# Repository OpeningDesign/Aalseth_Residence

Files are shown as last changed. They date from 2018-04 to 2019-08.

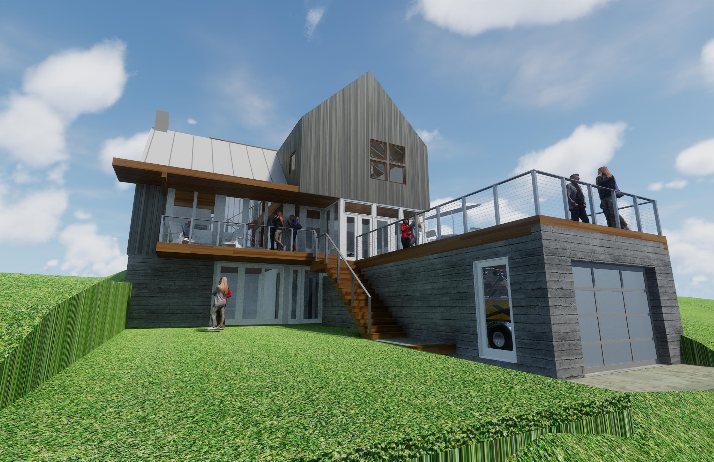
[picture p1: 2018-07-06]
Transfer/20180706 - owner review/jpgs/20180706 - Aalseth_Residence - Schematic Drawings Page 012.jpg

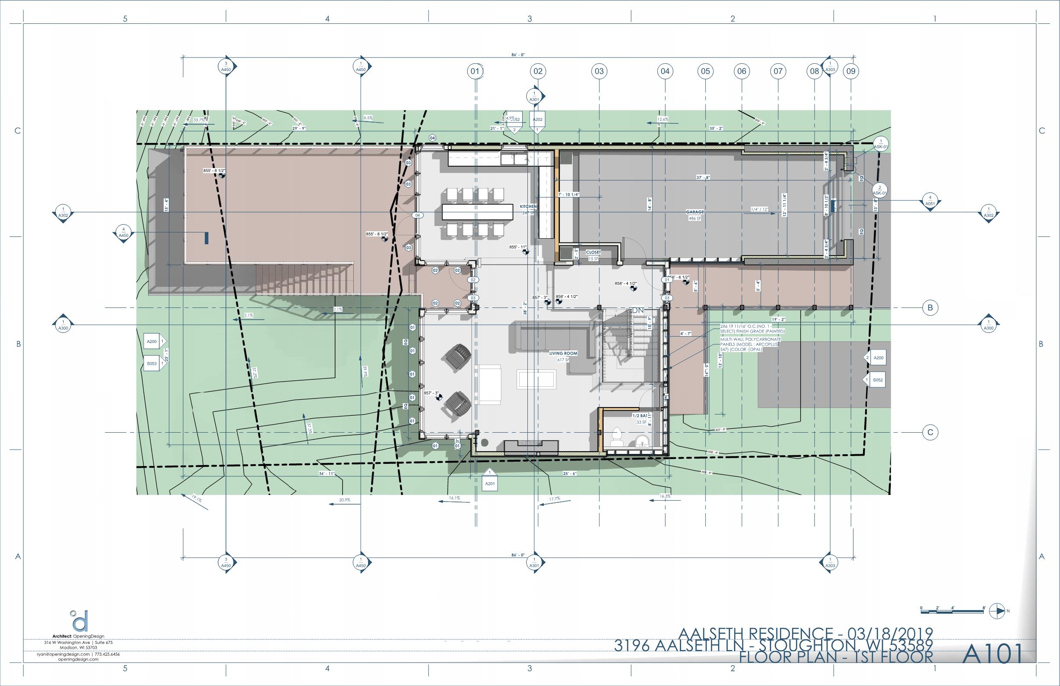
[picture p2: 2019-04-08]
Transfer/20190321 - to lumber yard - latest plans with door and window schedule/20190318 - 3196 Aalseth Lane Page 002.jpg

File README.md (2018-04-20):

---
#### In-the-Open

All of [OpeningDesign's](http://openingdesign.com/) projects are conducted out in the open.  That is, during the development of any one project, all team communication and content is hosted [publicly](https://github.com/OpeningDesign) (here on GitHub) and is <a href="#license">open source</a>.

Our [about page](http://openingdesign.com/about/) provides a more nuanced description of this open approach.

---
#### License
Per usual, unless otherwise noted, all content associated with [OpeningDesign](http://openingdesign.com) projects is licensed under an open source, 'copyleft' license: 
[Attribution-ShareAlike 4.0 International (CC BY-SA 4.0)](https://creativecommons.org/licenses/by-sa/4.0/).  Attribution to be given to the entire team associated with the project.


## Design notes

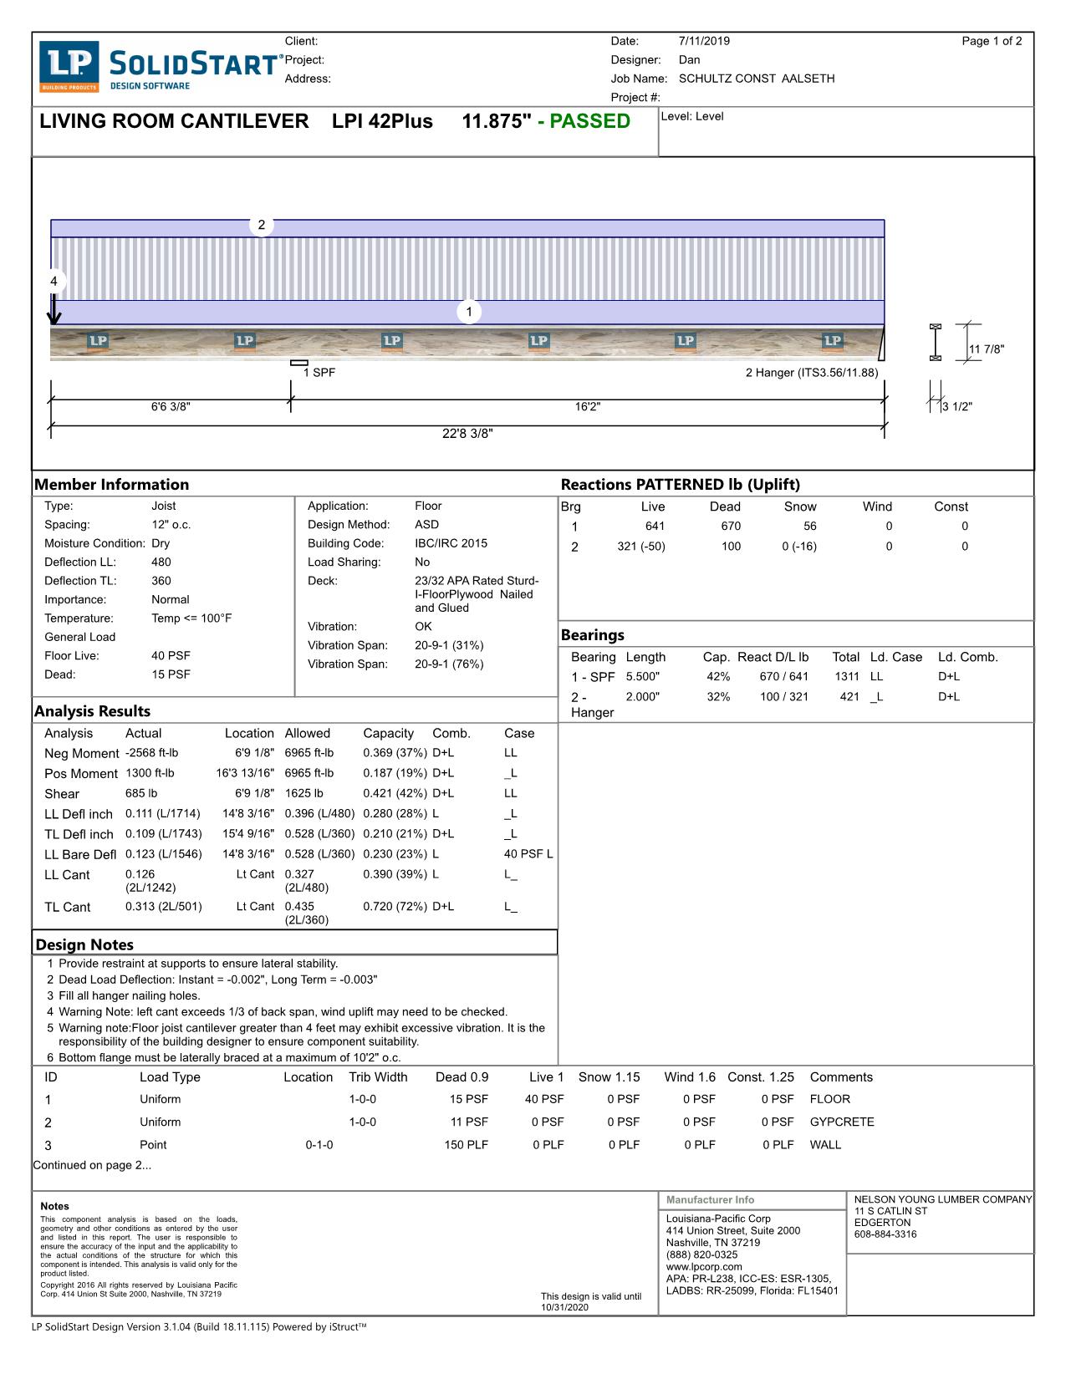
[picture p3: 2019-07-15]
Transfer/20190711 - from Lumber Yard - TJI spec/SCHULTZ AALSETH LIVING ROOM JOIST CANTILEVER Page 001.jpg

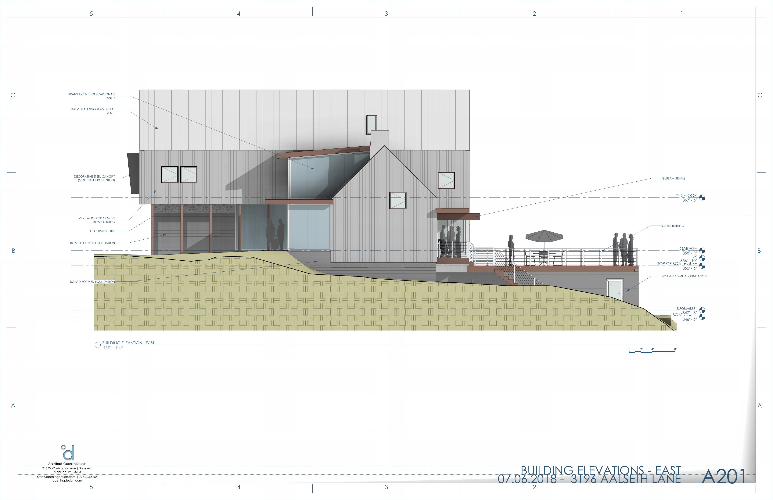
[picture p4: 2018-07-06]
Transfer/20180706 - owner review/jpgs/20180706 - Aalseth_Residence - Schematic Drawings Page 006.jpg

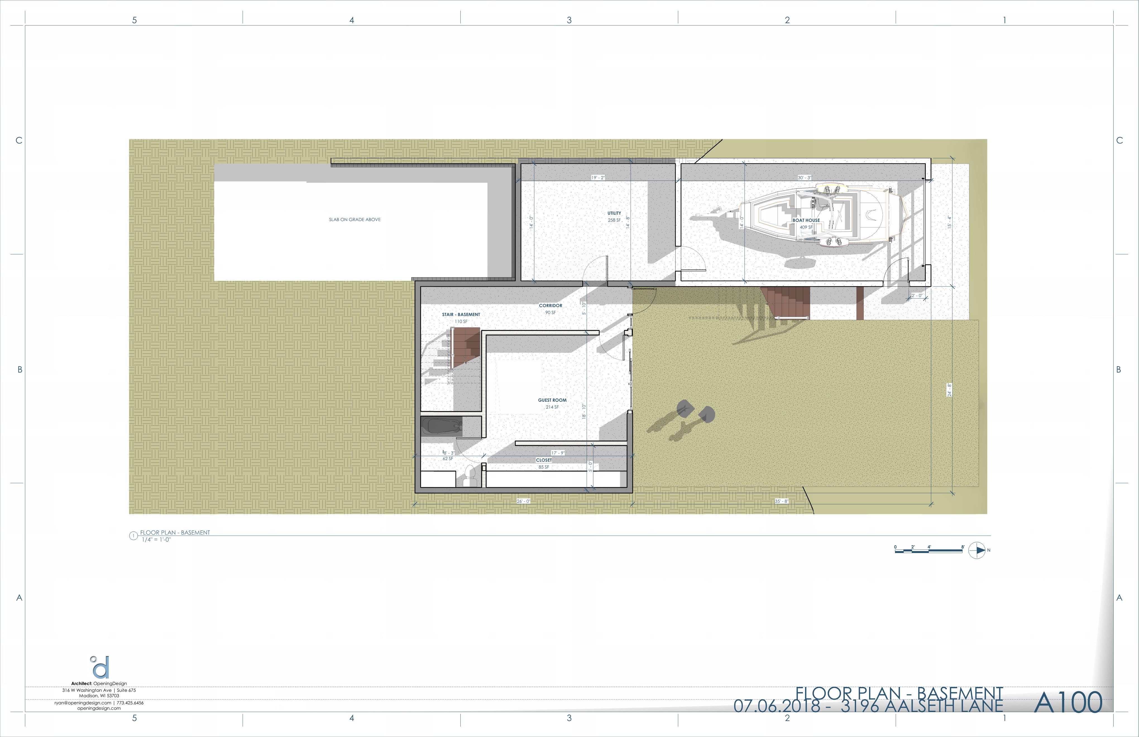
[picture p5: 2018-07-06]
Transfer/20180706 - owner review/jpgs/20180706 - Aalseth_Residence - Schematic Drawings Page 002.jpg

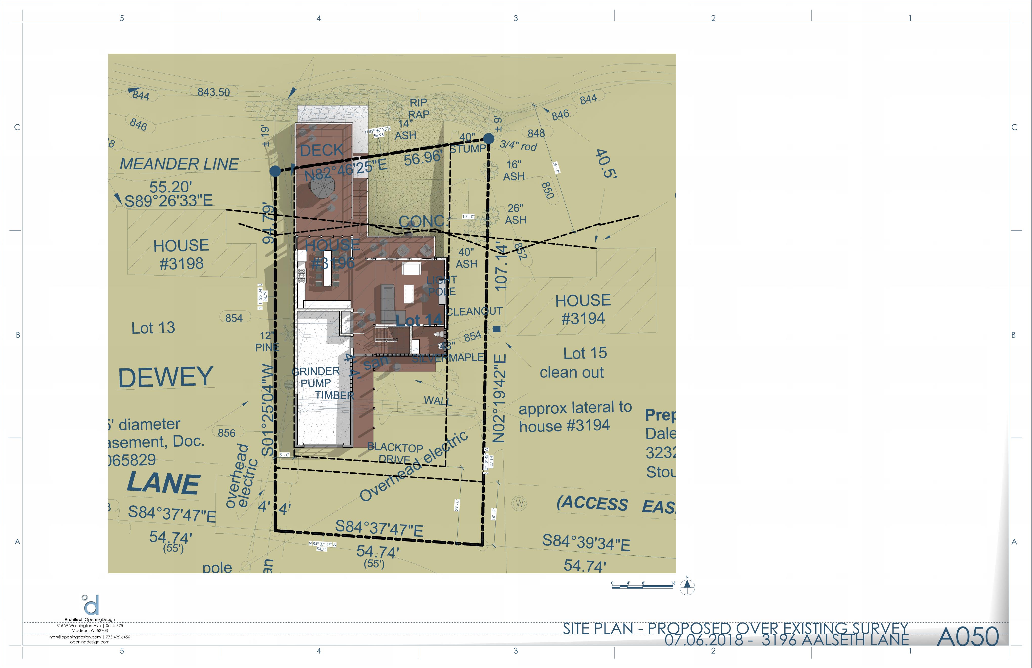
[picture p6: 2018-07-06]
Transfer/20180706 - owner review/jpgs/20180706 - Aalseth_Residence - Schematic Drawings Page 001.jpg

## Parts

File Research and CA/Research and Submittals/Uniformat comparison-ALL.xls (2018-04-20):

A | Substructure | 1 |  |  | A | Substructure | 1 |  | 21-01 00 00 | Substructure
B | Shell | 1 |  |  | A2010310 | Shoring | 5 | -2001300 | 21-02 00 00 | Shell
C | Interiors | 1 |  |  | B1020230 | Beams - Steel | 5 | -2001320 | 21-03 00 00 | Interiors
D | Services | 1 |  |  | B2030900 | Other Exterior Doors | 4 | -2000023 | 21-04 00 00 | Services
E | Equipment and Furnishings | 1 |  |  | D1020110 | Escalators | 5 | -2001350 | 21-05 00 00 | Equipment and Furnishings
F | Special Construction and Demolition | 1 |  |  | D2040 | Rain Water Drainage | 3 | -2001160 | 21-06 00 00 | Special Construction and Demolition
G | Sitework | 1 |  |  | D3090 | Other HVAC Systems/Equip | 3 | -2001140 | 21-07 00 00 | Sitework
A10 | Foundations | 2 | 0 |  | A10 | Foundations | 2 |  | 21-01 10 | Foundations
A20 | Subgrade Enclosures | 2 | 0 |  | A1020100 | Pile Foundations | 4 | -2001300 | 21-01 20 | Subgrade Enclosures
A40 | Slabs-On-Grade | 2 | 0 |  | A1020150 | Piles - Step Tapered | 5 | -2001300 | 21-01 40 | Slabs-On-Grade
A60 | Water and Gas Mitigation | 2 | 0 |  | A1020900 | Other Special Foundation Conditions | 4 | -2001300 | 21-01 60 | Water and Gas Mitigation
A90 | Substructure Related Activities | 2 | 0 |  | A1030400 | Trenches | 4 | -2001300 | 21-01 90 | Substructure Related Activities
B10 | Superstructure | 2 | 0 |  | A2020 | Basement Walls | 3 |  | 21-02 10 | Superstructure
B20 | Exterior Vertical Enclosures | 2 | 0 |  | B1010245 | Columns - Precast | 5 | -2001330 | 21-02 20 | Exterior Vertical Enclosures
B30 | Exterior Horizontal Enclosures | 2 | 0 |  | B1010480 | Wood Beams w/ Wood Joists | 5 | -2001320 | 21-02 30 | Exterior Horizontal Enclosures
C10 | Interior Construction | 2 | 0 |  | B1020240 | Beams - Wood (Dimensional Lumber) | 5 | -2001320 | 21-03 10 | Interior Construction
C20 | Interior Finishes | 2 | 0 |  | B2010152 | Ext. Wall - Brick (Double Wythe) | 5 | -2000011 | 21-03 20 | Interior Finishes
D10 | Conveying | 2 | 0 |  | B30 | Roofing | 2 |  | 21-04 10 | Conveying
D20 | Plumbing | 2 | 0 |  | B3020300 | Gravity Roof Ventilators | 4 | -2001140 | 21-04 20 | Plumbing
D30 | Heating, Ventilation, and Air Conditioning (HVAC) | 2 | 0 |  | C1010600 | Interior Balustrades & Screens | 4 | -2000126 | 21-04 30 | Heating, Ventilation, and Air Conditioning (HVAC)
D40 | Fire Protection | 2 | 0 |  | C1030400 | Fabricated Cabinets & Counters | 4 | -2001000 | 21-04 40 | Fire Protection
D50 | Electrical | 2 | 0 |  | C1030900 | Other Fittings | 4 | -2001350 | 21-04 50 | Electrical
D60 | Communications | 2 | 0 |  | C3020100 | Floor Toppings & Coatings | 4 | -2000032 | 21-04 60 | Communications
D70 | Electronic Safety and Security | 2 | 0 |  | C3030 | Ceiling Finishes | 3 |  | 21-04 70 | Electronic Safety and Security
D80 | Integrated Automation | 2 | 0 |  | D1010100 | Passenger Elevators | 4 | -2001350 | 21-04 80 | Integrated Automation
E10 | Equipment | 2 | 0 |  | D1020200 | Moving Walks | 4 | -2001350 | 21-05 10 | Equipment
E20 | Furnishings | 2 | 0 |  | D2010820 | Water Coolers | 5 | -2001160 | 21-05 20 | Furnishings
F10 | Special Construction | 2 | 0 |  | D2040100 | Pipe & Fittings | 4 | -2001160 | 21-06 10 | Special Construction
F20 | Facility Remediation | 2 | 0 |  | D3040400 | Hot Water Distribution | 4 | -2001140 | 21-06 20 | Facility Remediation
F30 | Demolition | 2 | 0 |  | D3060 | Controls & Instrumentation | 3 | -2001140 | 21-06 30 | Demolition
G10 | Site Preparation | 2 | 0 |  | D3090100 | Special Cooling Systems & Devices | 4 | -2001140 | 21-07 10 | Site Preparation
G20 | Site Improvements | 2 | 0 |  | D5020110 | Receptacles - Wall | 5 | -2001060 | 21-07 20 | Site Improvements
G30 | Liquid and Gas Site Utilities | 2 | 0 |  | E1020300 | Theater & Stage Equipment | 4 | -2001350 | 21-07 30 | Liquid and Gas Site Utilities
G40 | Electrical Site Improvements | 2 | 0 |  | E20 | Furnishings | 2 |  | 21-07 40 | Electrical Site Improvements
G50 | Site Communications | 2 | 0 |  | E2020300 | Movable Rugs & Mats | 4 | -2000080 | 21-07 50 | Site Communications
G90 | Miscellaneous Site Construction | 2 | 0 |  | F1010 | Special Structures | 3 |  | 21-07 90 | Miscellaneous Site Construction
A1010 | Standard Foundations | 3 | 0 |  | A1010 | Standard Foundations | 3 |  | 21-01 10 10 | Standard Foundations
A1020 | Special Foundations | 3 | 0 |  | A1010130 | Pile Caps | 5 | -2001300 | 21-01 10 20 | Special Foundations
A2010 | Walls for Subgrade Enclosures | 3 | 0 |  | A1020110 | Piles - CIP | 5 | -2001300 | 21-01 20 10 | Walls for Subgrade Enclosures
A4010 | Standard Slabs-on-Grade | 3 | 0 |  | A1020160 | Piles - Treated Wood | 5 | -2001300 | 21-01 40 10 | Standard Slabs-on-Grade
A4020 | Structural Slabs-on-Grade | 3 | 0 |  | A1020200 | Grade Beams | 4 | -2001300 | 21-01 40 20 | Structural Slabs-on-Grade
A4030 | Slab Trenches | 3 | 0 |  | A1020210 | Grade Beams - CIP | 5 | -2001300 | 21-01 40 30 | Slab Trenches
A4040 | Pits and Bases | 3 | 0 |  | A1020300 | Caissons | 4 | -2001300 | 21-01 40 40 | Pits and Bases
A4090 | Slab-On-Grade Supplementary Components | 3 | 0 |  | A1020310 | Caissons - Bell | 5 | -2001300 | 21-01 40 90 | Slab-On-Grade Supplementary Components
A6010 | Building Subdrainage | 3 | 0 |  | A1030 | Slab on Grade | 3 |  | 21-01 60 10 | Building Subdrainage
A6020 | Off-Gassing Mitigation | 3 | 0 |  | A1030120 | SOG - Unreinforced | 5 | -2000032 | 21-01 60 20 | Off-Gassing Mitigation
A9010 | Substructure Excavation | 3 | 0 |  | A1030500 | Pits & Bases | 4 | -2001300 | 21-01 90 10 | Substructure Excavation
A9020 | Construction Dewatering | 3 | 0 |  | A1030700 | Under-Slab Insulation | 4 | -2000032 | 21-01 90 20 | Construction Dewatering
A9030 | Excavation Support | 3 | 0 |  | A1030710 | Subdrainage Piping | 5 | -2001160 | 21-01 90 30 | Excavation Support
A9040 | Soil Treatment | 3 | 0 |  | A2010300 | Shoring | 4 | -2001300 | 21-01 90 40 | Soil Treatment
B1010 | Floor Construction | 3 | 0 |  | A2020100 | Basement Wall Construction | 4 | -2000011 | 21-02 10 10 | Floor Construction
B1020 | Roof Construction | 3 | 0 |  | A2020310 | Basement Wall Insulation - Rigid | 5 | -2000011 | 21-02 10 20 | Roof Construction
B1080 | Stairs | 3 | 0 |  | B1010100 | Suspended Basement Floor Construction | 4 | -2000032 | 21-02 10 80 | Stairs
B2010 | Exterior Walls | 3 | 0 |  | B1010250 | Columns - Steel | 5 | -2001330 | 21-02 20 10 | Exterior Walls
B2020 | Exterior Windows | 3 | 0 |  | B1010350 | Joists - Steel | 5 | -2001320 | 21-02 20 20 | Exterior Windows
B2050 | Exterior Doors and Grilles | 3 | 0 |  | B1010380 | Planks - Precast | 5 | -2000032 | 21-02 20 50 | Exterior Doors and Grilles
B2070 | Exterior Louvers and Vents | 3 | 0 |  | B1010422 | CIP Beam & Slab - Two Way | 5 | -2001320 | 21-02 20 70 | Exterior Louvers and Vents
B2080 | Exterior Wall Appurtenances | 3 | 0 |  | B1010434 | W Shape Composite Deck & Slab | 5 | -2001320 | 21-02 20 80 | Exterior Wall Appurtenances
B2090 | Exterior Wall Specialties | 3 | 0 |  | B1010470 | Steel Light Gauge Floor System | 5 | -2001320 | 21-02 20 90 | Exterior Wall Specialties
B3010 | Roofing | 3 | 0 |  | B1010482 | Wood Laminated Beams w/ Wood Joists | 5 | -2001320 | 21-02 30 10 | Roofing
B3020 | Roof Appurtenances | 3 | 0 |  | B1010900 | Fireproofing - Floor Construction | 4 | -2000032 | 21-02 30 20 | Roof Appurtenances
B3040 | Traffic Bearing Horizontal Enclosures | 3 | 0 |  | B1020100 | Flat Roof Framing - Vertical Elements | 4 | -2000011 | 21-02 30 40 | Traffic Bearing Horizontal Enclosures
B3060 | Horizontal Openings | 3 | 0 |  | B1020140 | Columns - CIP | 5 | -2001330 | 21-02 30 60 | Horizontal Openings
B3080 | Overhead Exterior Enclosures | 3 | 0 |  | B1020200 | Flat Roof Framing - Horizontal Elements | 4 | -2001320 | 21-02 30 80 | Overhead Exterior Enclosures
C1010 | Interior Partitions | 3 | 0 |  | B1020245 | Beams - Wood (Laminated) | 5 | -2001320 | 21-03 10 10 | Interior Partitions
C1020 | Interior Windows | 3 | 0 |  | B1020300 | Flat Roof Framing - Systems | 4 | -2000035 | 21-03 10 20 | Interior Windows
C1030 | Interior Doors | 3 | 0 |  | B1020318 | CIP Slabs - Waffle | 5 | -2000035 | 21-03 10 30 | Interior Doors
C1040 | Interior Grilles and Gates | 3 | 0 |  | B1020364 | Joist Girders w/ Steel Joists | 5 | -2001320 | 21-03 10 40 | Interior Grilles and Gates
C1060 | Raised Floor Construction | 3 | 0 |  | B1020382 | Wood Laminated Beams w/ Wood Joists | 5 | -2001320 | 21-03 10 60 | Raised Floor Construction
C1070 | Suspended Ceiling Construction | 3 | 0 |  | B1020600 | Dome Construction | 4 | -2000035 | 21-03 10 70 | Suspended Ceiling Construction
C1090 | Interior Specialties | 3 | 0 |  | B20 | Exterior Enclosure | 2 |  | 21-03 10 90 | Interior Specialties
C2010 | Wall Finishes | 3 | 0 |  | B2010154 | Ext. Wall - Brick Cavity | 5 | -2000011 | 21-03 20 10 | Wall Finishes
C2020 | Interior Fabrications | 3 | 0 |  | B2010400 | Exterior Sun Control Devices | 4 | -2001140 | 21-03 20 20 | Interior Fabrications
C2030 | Flooring | 3 | 0 |  | B2010500 | Balcony Walls & Handrails | 4 | -2000126 | 21-03 20 30 | Flooring
C2040 | Stair Finishes | 3 | 0 |  | B2030100 | Glazed Doors & Entrances | 4 | -2000023 | 21-03 20 40 | Stair Finishes
C2050 | Ceiling Finishes | 3 | 0 |  | B2030230 | Exterior Solid Doors - Wood | 5 | -2000023 | 21-03 20 50 | Ceiling Finishes
D1010 | Vertical Conveying Systems | 3 | 0 |  | B3010 | Roof Coverings | 3 |  | 21-04 10 10 | Vertical Conveying Systems
D1030 | Horizontal Conveying | 3 | 0 |  | B3010150 | Roofing - Shingle & Tile | 5 | -2000035 | 21-04 10 30 | Horizontal Conveying
D1050 | Material Handling | 3 | 0 |  | B3010410 | Base Flashing | 5 | -2000035 | 21-04 10 50 | Material Handling
D1080 | Operable Access Systems | 3 | 0 |  | B3020100 | Glazed Roof Openings | 4 | -2000014 | 21-04 10 80 | Operable Access Systems
D2010 | Domestic Water Distribution | 3 | 0 |  | C | Interiors | 1 |  | 21-04 20 10 | Domestic Water Distribution
D2020 | Sanitary Drainage | 3 | 0 |  | C1010118 | Partitions - Stone Veneer w/ Stud | 5 | -2000011 | 21-04 20 20 | Sanitary Drainage
D2030 | Building Support Plumbing Systems | 3 | 0 |  | C1010140 | Partitions - Drywall w/ Wood Stud | 5 | -2000011 | 21-04 20 30 | Building Support Plumbing Systems
D2050 | General Service Compressed-Air | 3 | 0 |  | C1010190 | Partition Components - Drywall | 5 | -2000011 | 21-04 20 50 | General Service Compressed-Air
D2060 | Process Support Plumbing Systems | 3 | 0 |  | C1010195 | Partition Components - Plaster | 5 | -2000011 | 21-04 20 60 | Process Support Plumbing Systems
D3010 | Facility Fuel Systems | 3 | 0 |  | C1010700 | Interior Windows & Storefronts | 4 | -2000014 | 21-04 30 10 | Facility Fuel Systems
D3020 | Heating Systems | 3 | 0 |  | C1020110 | Interior Doors - Metal | 5 | -2000023 | 21-04 30 20 | Heating Systems
D3030 | Cooling Systems | 3 | 0 |  | C1020300 | Interior Doors with Frames | 4 | -2000023 | 21-04 30 30 | Cooling Systems
D3050 | Facility HVAC Distribution Systems | 3 | 0 |  | C1020500 | Interior Door Wall Opening Elements | 4 | -2000023 | 21-04 30 50 | Facility HVAC Distribution Systems
D3060 | Ventilation | 3 | 0 |  | C1030110 | Toilet Partitions | 5 | -2001160 | 21-04 30 60 | Ventilation
D3070 | Special Purpose HVAC Systems | 3 | 0 |  | C1030320 | Shelving | 5 | -2001350 | 21-04 30 70 | Special Purpose HVAC Systems
D4010 | Fire Suppression | 3 | 0 |  | C1030410 | Cabinets | 5 | -2001000 | 21-04 40 10 | Fire Suppression
D5010 | Facility Power Generation | 3 | 0 |  | C1030910 | Mailboxes | 5 | -2001350 | 21-04 50 10 | Facility Power Generation
D5020 | Electrical Service and Distribution | 3 | 0 |  | C2010200 | Curved Stairs | 4 | -2000120 | 21-04 50 20 | Electrical Service and Distribution
D5030 | General Purpose Electrical Power | 3 | 0 |  | C2020 | Stair Finishes | 3 |  | 21-04 50 30 | General Purpose Electrical Power
D5040 | Lighting | 3 | 0 |  | C30 | Interior Finishes | 2 |  | 21-04 50 40 | Lighting
D5080 | Miscellaneous Electrical Systems | 3 | 0 |  | C3010130 | Wall Finishes - Coverings | 5 | -2000011 | 21-04 50 80 | Miscellaneous Electrical Systems
D6010 | Data Communications | 3 | 0 |  | C3020110 | Concrete Toppings | 5 | -2000032 | 21-04 60 10 | Data Communications
D6020 | Voice Communications | 3 | 0 |  | C3020410 | Flooring - Sheet Goods | 5 | -2000032 | 21-04 60 20 | Voice Communications
D6030 | Audio-Video Communication | 3 | 0 |  | C3020500 | Carpeting | 4 | -2000032 | 21-04 60 30 | Audio-Video Communication
D6090 | Communications Supplementary Components | 3 | 0 |  | C3020800 | Subflooring & Underlayment | 4 | -2000032 | 21-04 60 90 | Communications Supplementary Components
D7010 | Access Control and Intrusion Detection | 3 | 0 |  | C3030100 | Applied Ceiling Finishes | 4 | -2000038 | 21-04 70 10 | Access Control and Intrusion Detection
D7030 | Electronic Surveillance | 3 | 0 |  | C3030130 | Ceiling Finishes - Coverings | 5 | -2000038 | 21-04 70 30 | Electronic Surveillance
D7050 | Detection and Alarm | 3 | 0 |  | C3030200 | Suspended Ceilings | 4 | -2000038 | 21-04 70 50 | Detection and Alarm
D7070 | Electronic Monitoring and Control | 3 | 0 |  | C3030900 | Other Ceiling Finishes | 4 | -2000038 | 21-04 70 70 | Electronic Monitoring and Control
D7090 | Electronic Safety and Security Supplementary Components | 3 | 0 |  | D10 | Conveying | 2 |  | 21-04 70 90 | Electronic Safety and Security Supplementary Components
D8010 | Integrated Automation Facility Controls | 3 | 0 |  | D1010110 | Elevators - Hydraulic | 5 | -2001350 | 21-04 80 10 | Integrated Automation Facility Controls
E1010 | Vehicle and Pedestrian Equipment | 3 | 0 |  | D1020210 | Moving Walks | 5 | -2001350 | 21-05 10 10 | Vehicle and Pedestrian Equipment
E1030 | Commercial Equipment | 3 | 0 |  | D1090400 | Conveyors | 4 | -2001350 | 21-05 10 30 | Commercial Equipment
E1040 | Institutional Equipment | 3 | 0 |  | D2010120 | Water Closets - Group | 5 | -2001160 | 21-05 10 40 | Institutional Equipment
E1060 | Residential Equipment | 3 | 0 |  | D2010320 | Lavatories - Battery Mount | 5 | -2001160 | 21-05 10 60 | Residential Equipment
E1070 | Entertainment and Recreational Equipment | 3 | 0 |  | D2010430 | Sinks - Laboratory | 5 | -2001160 | 21-05 10 70 | Entertainment and Recreational Equipment
E1090 | Other Equipment | 3 | 0 |  | D2010610 | Wash Fountains - Group | 5 | -2001160 | 21-05 10 90 | Other Equipment
E2010 | Fixed Furnishings | 3 | 0 |  | D2010900 | Other Plumbing Fixtures | 4 | -2001160 | 21-05 20 10 | Fixed Furnishings
E2050 | Movable Furnishings | 3 | 0 |  | D2030 | Sanitary Waste | 3 | -2001160 | 21-05 20 50 | Movable Furnishings
F1010 | Integrated Construction | 3 | 0 |  | D2040200 | Roof Drains | 4 | -2001160 | 21-06 10 10 | Integrated Construction
F1020 | Special Structures | 3 | 0 |  | D2090100 | Gas Distribution | 4 | -2001160 | 21-06 10 20 | Special Structures
F1030 | Special Function Construction | 3 | 0 |  | D30 | HVAC | 2 |  | 21-06 10 30 | Special Function Construction
F1050 | Special Facility Components | 3 | 0 |  | D3010300 | Coal Supply System | 4 | -2001140 | 21-06 10 50 | Special Facility Components
F1060 | Athletic and Recreational Special Construction | 3 | 0 |  | D3020100 | Boilers | 4 | -2001140 | 21-06 10 60 | Athletic and Recreational Special Construction
F1080 | Special Instrumentation | 3 | 0 |  | D3030300 | Other Cooling System Components | 4 | -2001140 | 21-06 10 80 | Special Instrumentation
F2010 | Hazardous Materials Remediation | 3 | 0 |  | D3040500 | Chilled Water Distribution | 4 | -2001140 | 21-06 20 10 | Hazardous Materials Remediation
F3010 | Structure Demolition | 3 | 0 |  | D3060100 | Heating Generating Systems | 4 | -2001140 | 21-06 30 10 | Structure Demolition
F3030 | Selective Demolition | 3 | 0 |  | D3060600 | Terminal Devices | 4 | -2001140 | 21-06 30 30 | Selective Demolition
F3050 | Structure Moving | 3 | 0 |  | D3070200 | Air System Testing & Balancing | 4 | -2001140 | 21-06 30 50 | Structure Moving
G1010 | Site Clearing | 3 | 0 |  | D3090200 | Special Humidity Control | 4 | -2001140 | 21-07 10 10 | Site Clearing
G1020 | Site Elements Demolition | 3 | 0 |  | D3090600 | Paint Spray Booth Ventilation | 4 | -2001140 | 21-07 10 20 | Site Elements Demolition
G1030 | Site Element Relocations | 3 | 0 |  | D4010 | Sprinklers | 3 |  | 21-07 10 30 | Site Element Relocations
G1050 | Site Remediation | 3 | 0 |  | D4010200 | Sprinkler Pumping Equipment | 4 | -2001160 | 21-07 10 50 | Site Remediation
G1070 | Site Earthwork | 3 | 0 |  | D4030900 | Other Fire Protection Specialties | 4 | -2001350 | 21-07 10 70 | Site Earthwork
G2010 | Roadways | 3 | 0 |  | D5020115 | Receptacles - Floor | 5 | -2001060 | 21-07 20 10 | Roadways
G2020 | Parking Lots | 3 | 0 |  | D5020280 | Light Poles | 5 | -2001120 | 21-07 20 20 | Parking Lots
G2030 | Pedestrian Plazas and Walkways | 3 | 0 |  | D5030500 | Television Systems | 4 | -2001040 | 21-07 20 30 | Pedestrian Plazas and Walkways
G2040 | Airfields | 3 | 0 |  | D5090200 | Emergency Light & Power Systems | 4 | -2001040 | 21-07 20 40 | Airfields
G2050 | Athletic, Recreational, and Playfield Areas | 3 | 0 |  | E1010 | Commercial Equipment | 3 |  | 21-07 20 50 | Athletic, Recreational, and Playfield Areas
G2060 | Site Development | 3 | 0 |  | E1010200 | Teller & Service Equipment | 4 | -2001350 | 21-07 20 60 | Site Development
G2080 | Landscaping | 3 | 0 |  | E1020100 | Ecclesiastical Equipment | 4 | -2001350 | 21-07 20 80 | Landscaping
G3010 | Water Utilities | 3 | 0 |  | E1020310 | Theater Equipment - Projection | 5 | -2001350 | 21-07 30 10 | Water Utilities
G3020 | Sanitary Sewerage Utilities | 3 | 0 |  | E1020500 | Audio-visual Equipment | 4 | -2001350 | 21-07 30 20 | Sanitary Sewerage Utilities
G3030 | Storm Drainage Utilities | 3 | 0 |  | E1020800 | Medical Equipment | 4 | -2001350 | 21-07 30 30 | Storm Drainage Utilities
G3050 | Site Energy Distribution | 3 | 0 |  | E1030900 | Other Vehicular Equipment | 4 | -2001350 | 21-07 30 50 | Site Energy Distribution
G3060 | Site Fuel Distribution | 3 | 0 |  | E1090300 | Food Service Equipment | 4 | -2001350 | 21-07 30 60 | Site Fuel Distribution
G3090 | Liquid and Gas Site Utilities Supplementary Components | 3 | 0 |  | E1090600 | Window Washing Equipment | 4 | -2001350 | 21-07 30 90 | Liquid and Gas Site Utilities Supplementary Components
G4010 | Site Electric Distribution Systems | 3 | 0 |  | E2010 | Fixed Furnishings | 3 |  | 21-07 40 10 | Site Electric Distribution Systems
G4050 | Site Lighting | 3 | 0 |  | E2010500 | Fixed Multiple Seating | 4 | -2000080 | 21-07 40 50 | Site Lighting
G5010 | Site Communications Systems | 3 | 0 |  | E2020400 | Movable Multiple Seating | 4 | -2000080 | 21-07 50 10 | Site Communications Systems
G9010 | Tunnels | 3 | 0 |  | F1010100 | Air Supported Structures | 4 | -2001320 | 21-07 90 10 | Tunnels
A1010.10 | Wall Foundations | 4 |  |  | A1010100 | Footings & Pile Caps | 4 | -2001300 | 21-01 10 10 10 | Wall Foundations
A1010.30 | Column Foundations | 4 |  |  | A1010110 | Strip Footings | 5 | -2001300 | 21-01 10 10 30 | Column Foundations
A1010.90 | Standard Foundation Supplementary Components | 4 |  |  | A1010120 | Spread Footings | 5 | -2001300 | 21-01 10 10 90 | Standard Foundation Supplementary Components
A1020.10 | Driven Piles | 4 |  |  | A1010200 | Foundation Walls | 4 | -2000011 | 21-01 10 20 10 | Driven Piles
A1020.15 | Bored Piles | 4 |  |  | A1010210 | Foundation Walls - CIP | 5 | -2000011 | 21-01 10 20 15 | Bored Piles
A1020.20 | Caissons | 4 |  |  | A1010220 | Foundation Walls - CMU | 5 | -2000011 | 21-01 10 20 20 | Caissons
A1020.30 | Special Foundation Walls | 4 |  |  | A1010230 | Foundation Walls - Wood | 5 | -2000011 | 21-01 10 20 30 | Special Foundation Walls
A1020.40 | Foundation Anchors | 4 |  |  | A1010300 | Perimeter Drainage | 4 | -2001160 | 21-01 10 20 40 | Foundation Anchors
A1020.50 | Underpinning | 4 |  |  | A1010310 | Footing Drains | 5 | -2001160 | 21-01 10 20 50 | Underpinning
A1020.60 | Raft Foundations | 4 |  |  | A1010400 | Perimeter Insulation | 4 | -2000011 | 21-01 10 20 60 | Raft Foundations
A1020.70 | Pile Caps | 4 |  |  | A1010410 | Perimeter Insulation - Rigid | 5 | -2000011 | 21-01 10 20 70 | Pile Caps
A1020.80 | Grade Beams | 4 |  |  | A1020 | Special Foundations | 3 |  | 21-01 10 20 80 | Grade Beams
A2010.10 | Subgrade Enclosure Wall Construction | 4 |  |  | A1020120 | Piles - Precast Concrete | 5 | -2001300 | 21-01 20 10 10 | Subgrade Enclosure Wall Construction
A2010.20 | Subgrade Enclosure Wall Interior Skin | 4 |  |  | A1020130 | Piles - Steel Pipe | 5 | -2001300 | 21-01 20 10 20 | Subgrade Enclosure Wall Interior Skin
A2010.90 | Subgrade Enclosure Wall Supplementary Components | 4 |  |  | A1020140 | Piles - Steel H | 5 | -2001300 | 21-01 20 10 90 | Subgrade Enclosure Wall Supplementary Components
A4090.10 | Perimeter Insulation | 4 |  |  | A1020400 | Underpinning | 4 | -2001300 | 21-01 40 90 10 | Perimeter Insulation
A4090.20 | Vapor Retarder | 4 |  |  | A1020500 | Dewatering | 4 | -2001260 | 21-01 40 90 20 | Vapor Retarder
A4090.30 | Waterproofing | 4 |  |  | A1020600 | Raft Foundations | 4 | -2001300 | 21-01 40 90 30 | Waterproofing
A4090.50 | Mud Slab | 4 |  |  | A1020700 | Pressure Injected Grouting | 4 | -2001300 | 21-01 40 90 50 | Mud Slab
A4090.60 | Subbase Layer | 4 |  |  | A1020710 | Pressure Injected Footings | 5 | -2001300 | 21-01 40 90 60 | Subbase Layer
A6010.10 | Foundation Drainage | 4 |  |  | A1030100 | Standard Slab on Grade | 4 | -2000032 | 21-01 60 10 10 | Foundation Drainage
A6010.20 | Underslab Drainage | 4 |  |  | A1030110 | SOG - Reinforced | 5 | -2000032 | 21-01 60 10 20 | Underslab Drainage
A6020.10 | Radon Mitigation | 4 |  |  | A1030200 | Structural Slab on Grade | 4 | -2000032 | 21-01 60 20 10 | Radon Mitigation
A6020.50 | Methane Mitigation | 4 |  |  | A1030300 | Inclined Slab on Grade | 4 | -2000032 | 21-01 60 20 50 | Methane Mitigation
A9010.10 | Backfill and Compaction | 4 |  |  | A1030600 | Under-Slab Drainage | 4 | -2001160 | 21-01 90 10 10 | Backfill and Compaction
A9030.10 | Anchor Tiebacks | 4 |  |  | A20 | Basement Construction | 2 |  | 21-01 90 30 10 | Anchor Tiebacks
A9030.20 | Cofferdams | 4 |  |  | A2010 | Basement Excavation | 3 |  | 21-01 90 30 20 | Cofferdams
A9030.40 | Cribbing and Walers | 4 |  |  | A2010100 | Excavation for Basements | 4 | -2001300 | 21-01 90 30 40 | Cribbing and Walers
A9030.60 | Ground Freezing | 4 |  |  | A2010110 | Basement Excavation & Backfill | 5 | -2001300 | 21-01 90 30 60 | Ground Freezing
A9030.70 | Slurry Walls | 4 |  |  | A2010200 | Structural Backfill & Compaction | 4 | -2001300 | 21-01 90 30 70 | Slurry Walls
B1010.10 | Floor Structural Frame | 4 |  |  | A2020110 | Basement Walls - CIP | 5 | -2000011 | 21-02 10 10 10 | Floor Structural Frame
B1010.20 | Floor Decks, Slabs, and Toppings | 4 |  |  | A2020120 | Basement Walls - CMU | 5 | -2000011 | 21-02 10 10 20 | Floor Decks, Slabs, and Toppings
B1010.30 | Balcony Floor Construction | 4 |  |  | A2020130 | Basement Walls - Wood | 5 | -2000011 | 21-02 10 10 30 | Balcony Floor Construction
B1010.40 | Mezzanine Floor Construction | 4 |  |  | A2020200 | Moisture Protection | 4 | -2000011 | 21-02 10 10 40 | Mezzanine Floor Construction
B1010.50 | Ramps | 4 |  |  | A2020210 | Foundation Dampproofing | 5 | -2000011 | 21-02 10 10 50 | Ramps
B1010.90 | Floor Construction Supplementary Components | 4 |  |  | A2020300 | Basement Wall Insulation | 4 | -2000011 | 21-02 10 10 90 | Floor Construction Supplementary Components
B1020.10 | Roof Structural Frame | 4 |  |  | A2020400 | Interior Skin | 4 | -2000011 | 21-02 10 20 10 | Roof Structural Frame
B1020.20 | Roof Decks, Slabs, and Sheathing | 4 |  |  | B | Shell | 1 |  | 21-02 10 20 20 | Roof Decks, Slabs, and Sheathing
B1020.30 | Canopy Construction | 4 |  |  | B10 | Superstructure | 2 |  | 21-02 10 20 30 | Canopy Construction
B1020.90 | Roof Construction Supplementary Components | 4 |  |  | B1010 | Floor Construction | 3 |  | 21-02 10 20 90 | Roof Construction Supplementary Components
B1080.10 | Stair Construction | 4 |  |  | B1010200 | Upper Floor Framing - Vertical Elements | 4 | -2001330 | 21-02 10 80 10 | Stair Construction
B1080.30 | Stair Soffits | 4 |  |  | B1010210 | Bearing Walls - CIP | 5 | -2000011 | 21-02 10 80 30 | Stair Soffits
B1080.50 | Stair Railings | 4 |  |  | B1010215 | Bearing Walls - Block | 5 | -2000011 | 21-02 10 80 50 | Stair Railings
B1080.60 | Fire Escapes | 4 |  |  | B1010220 | Bearing Walls - Drywall w/Studs | 5 | -2000011 | 21-02 10 80 60 | Fire Escapes
B1080.70 | Metal Walkways | 4 |  |  | B1010225 | Bearing Walls - Plaster w/Studs | 5 | -2000011 | 21-02 10 80 70 | Metal Walkways
B1080.80 | Ladders | 4 |  |  | B1010240 | Columns - CIP | 5 | -2001330 | 21-02 10 80 80 | Ladders
B2010.10 | Exterior Wall Veneer | 4 |  |  | B1010255 | Columns - Wood | 5 | -2001330 | 21-02 20 10 10 | Exterior Wall Veneer
B2010.20 | Exterior Wall Construction | 4 |  |  | B1010300 | Upper Floor Framing - Horizontal Elements | 4 | -2001320 | 21-02 20 10 20 | Exterior Wall Construction
B2010.30 | Exterior Wall Interior Skin | 4 |  |  | B1010310 | Beams - CIP | 5 | -2001320 | 21-02 20 10 30 | Exterior Wall Interior Skin
B2010.40 | Fabricated Exterior Wall Assemblies | 4 |  |  | B1010320 | Beams - Precast | 5 | -2001320 | 21-02 20 10 40 | Fabricated Exterior Wall Assemblies
B2010.50 | Parapets | 4 |  |  | B1010325 | Beams - Precast Double T | 5 | -2001320 | 21-02 20 10 50 | Parapets
B2010.60 | Equipment Screens | 4 |  |  | B1010330 | Beams - Steel | 5 | -2001320 | 21-02 20 10 60 | Equipment Screens
B2010.80 | Exterior Wall Supplementary Components | 4 |  |  | B1010340 | Beams - Wood (Dimensional Lumber) | 5 | -2001320 | 21-02 20 10 80 | Exterior Wall Supplementary Components
B2010.90 | Exterior Wall Opening Supplementary Components | 4 |  |  | B1010345 | Beams - Wood (Laminated) | 5 | -2001320 | 21-02 20 10 90 | Exterior Wall Opening Supplementary Components
B2020.10 | Exterior Operating Windows | 4 |  |  | B1010355 | Joists - Wood (Dimensional Lumber) | 5 | -2001320 | 21-02 20 20 10 | Exterior Operating Windows
B2020.20 | Exterior Fixed Windows | 4 |  |  | B1010358 | Joists - Wood (Manufactured) | 5 | -2001320 | 21-02 20 20 20 | Exterior Fixed Windows
B2020.30 | Exterior Window Wall | 4 |  |  | B1010370 | Deck - Metal | 5 | -2000032 | 21-02 20 20 30 | Exterior Window Wall
B2020.50 | Exterior Special Function Windows | 4 |  |  | B1010375 | Deck - Wood | 5 | -2000032 | 21-02 20 20 50 | Exterior Special Function Windows
B2050.10 | Exterior Entrance Doors | 4 |  |  | B1010400 | Upper Floor Framing - Systems | 4 | -2001320 | 21-02 20 50 10 | Exterior Entrance Doors
B2050.20 | Exterior Utility Doors | 4 |  |  | B1010410 | CIP Slabs - One Way | 5 | -2000032 | 21-02 20 50 20 | Exterior Utility Doors
B2050.30 | Exterior Oversize Doors | 4 |  |  | B1010412 | CIP Slabs - Flat Plate | 5 | -2000032 | 21-02 20 50 30 | Exterior Oversize Doors
B2050.40 | Exterior Special Function Doors | 4 |  |  | B1010414 | CIP Slabs - Flat Plate w/Drop Panels | 5 | -2000032 | 21-02 20 50 40 | Exterior Special Function Doors
B2050.60 | Exterior Grilles | 4 |  |  | B1010416 | CIP Slabs - Multispan Joist | 5 | -2000032 | 21-02 20 50 60 | Exterior Grilles
B2050.70 | Exterior Gates | 4 |  |  | B1010418 | CIP Slabs - Waffle | 5 | -2000032 | 21-02 20 50 70 | Exterior Gates
B2050.90 | Exterior Door Supplementary Components | 4 |  |  | B1010420 | CIP Beam & Slab - One Way | 5 | -2001320 | 21-02 20 50 90 | Exterior Door Supplementary Components
B2070.10 | Exterior Louvers | 4 |  |  | B1010430 | Composite Beam & Slab | 5 | -2001320 | 21-02 20 70 10 | Exterior Louvers
B2070.50 | Exterior Vents | 4 |  |  | B1010432 | Composite Beam, Deck & Slab | 5 | -2001320 | 21-02 20 70 50 | Exterior Vents
B2080.10 | Exterior Fixed Grilles and Screens | 4 |  |  | B1010440 | Precast Beams w/ Precast Planks | 5 | -2001320 | 21-02 20 80 10 | Exterior Fixed Grilles and Screens
B2080.30 | Exterior Opening Protection Devices | 4 |  |  | B1010442 | Precast Beams w/Precast Double T | 5 | -2001320 | 21-02 20 80 30 | Exterior Opening Protection Devices
B2080.50 | Exterior Balcony Walls and Railings | 4 |  |  | B1010460 | Steel Girders w/ Steel Beams | 5 | -2001320 | 21-02 20 80 50 | Exterior Balcony Walls and Railings
B2080.70 | Exterior Fabrications | 4 |  |  | B1010462 | Steel Beams w/ Steel Joists | 5 | -2001320 | 21-02 20 80 70 | Exterior Fabrications
B2080.80 | Bird Control Devices | 4 |  |  | B1010464 | Joist Girders w/ Steel Joists | 5 | -2001320 | 21-02 20 80 80 | Bird Control Devices
B3010.10 | Steep Slope Roofing | 4 |  |  | B1010500 | Balcony Floor Construction | 4 | -2000032 | 21-02 30 10 10 | Steep Slope Roofing
B3010.50 | Low-Slope Roofing | 4 |  |  | B1010600 | Ramps | 4 | -2000180 | 21-02 30 10 50 | Low-Slope Roofing
B3010.70 | Canopy Roofing | 4 |  |  | B1010700 | Exterior Stairs & Fire Escapes | 4 | -2000120 | 21-02 30 10 70 | Canopy Roofing
B3010.90 | Roofing Supplementary Components | 4 |  |  | B1010800 | Floor Raceway Systems | 4 | -2000032 | 21-02 30 10 90 | Roofing Supplementary Components
B3020.10 | Roof Accessories | 4 |  |  | B1010910 | Steel Beam Fireproofing | 5 | -2001320 | 21-02 30 20 10 | Roof Accessories
B3020.30 | Roof Specialties | 4 |  |  | B1010920 | Steel Column Fireproofing | 5 | -2001320 | 21-02 30 20 30 | Roof Specialties
B3020.70 | Rainwater Management | 4 |  |  | B1020 | Roof Construction | 3 |  | 21-02 30 20 70 | Rainwater Management
B3040.10 | Traffic Bearing Coatings | 4 |  |  | B1020110 | Bearing Walls - CIP | 5 | -2000011 | 21-02 30 40 10 | Traffic Bearing Coatings
B3040.30 | Horizontal Waterproofing Membrane | 4 |  |  | B1020115 | Bearing Walls - Block | 5 | -2000011 | 21-02 30 40 30 | Horizontal Waterproofing Membrane
B3040.50 | Wear Surfaces | 4 |  |  | B1020120 | Bearing Walls - Drywall w/Studs | 5 | -2000011 | 21-02 30 40 50 | Wear Surfaces
B3040.90 | Horizontal Enclosure Supplementary Components | 4 |  |  | B1020125 | Bearing Walls - Plaster w/Studs | 5 | -2000011 | 21-02 30 40 90 | Horizontal Enclosure Supplementary Components
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

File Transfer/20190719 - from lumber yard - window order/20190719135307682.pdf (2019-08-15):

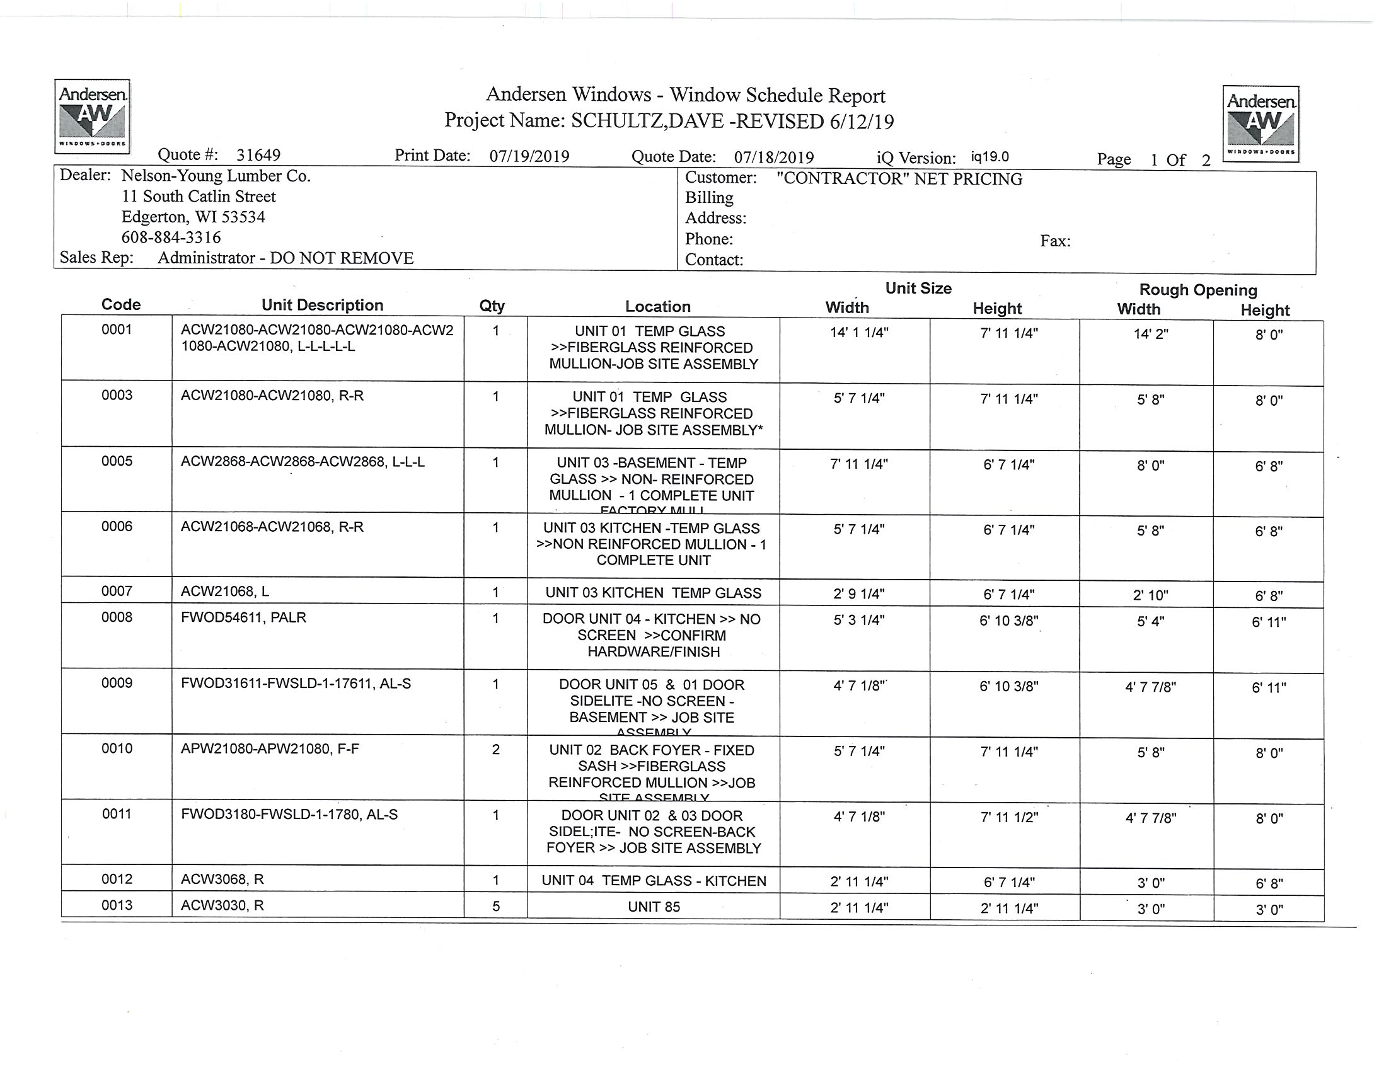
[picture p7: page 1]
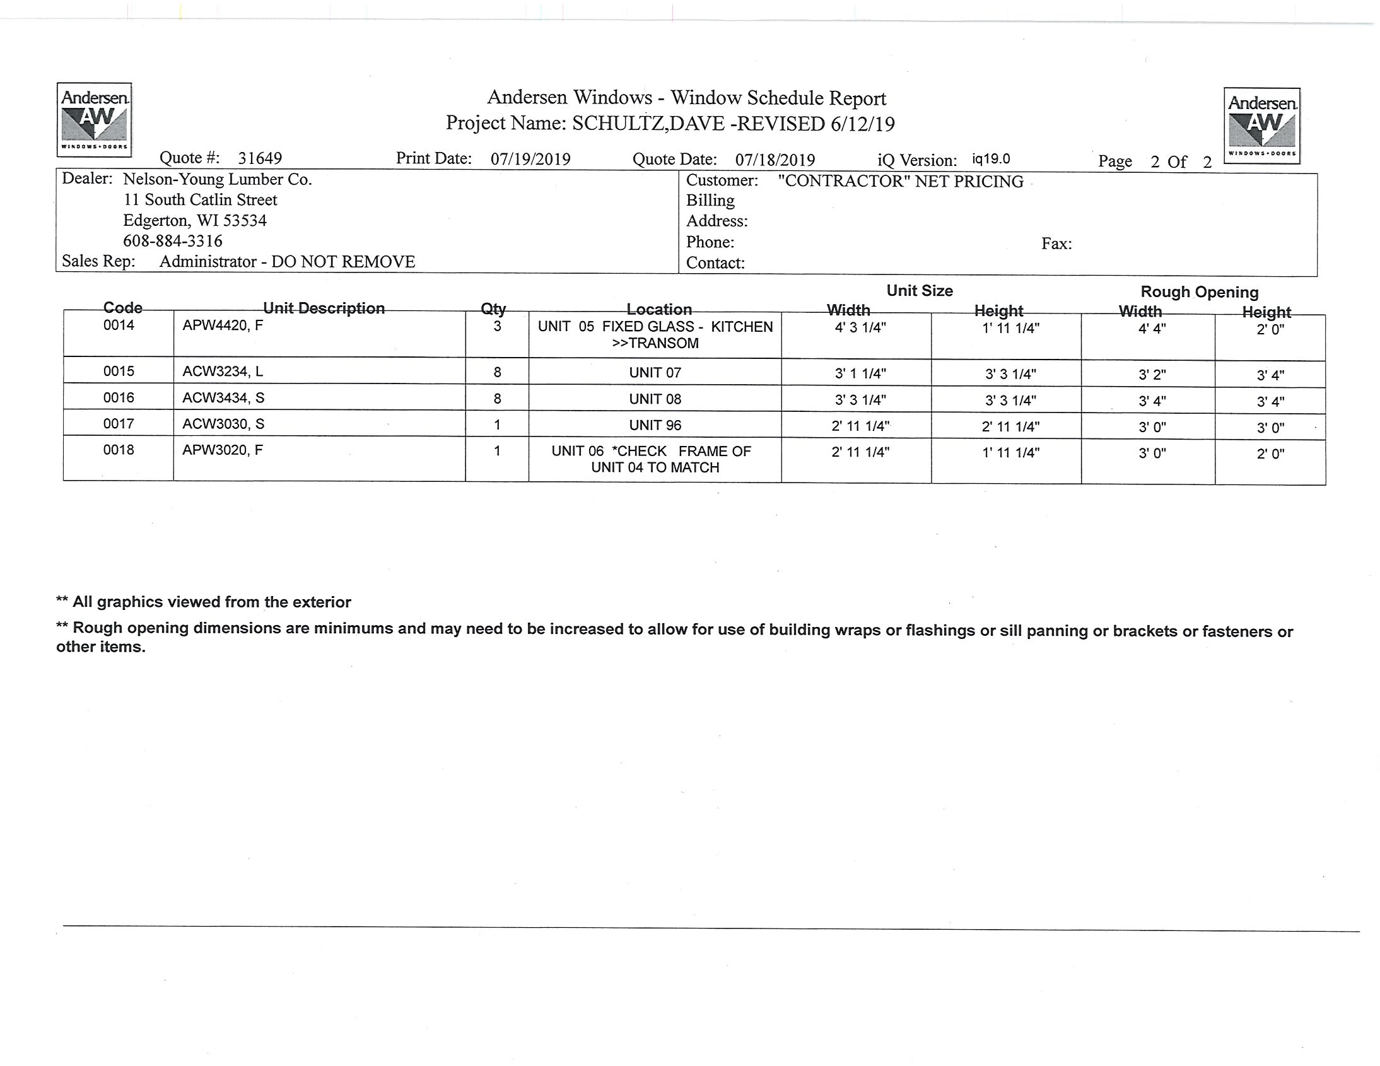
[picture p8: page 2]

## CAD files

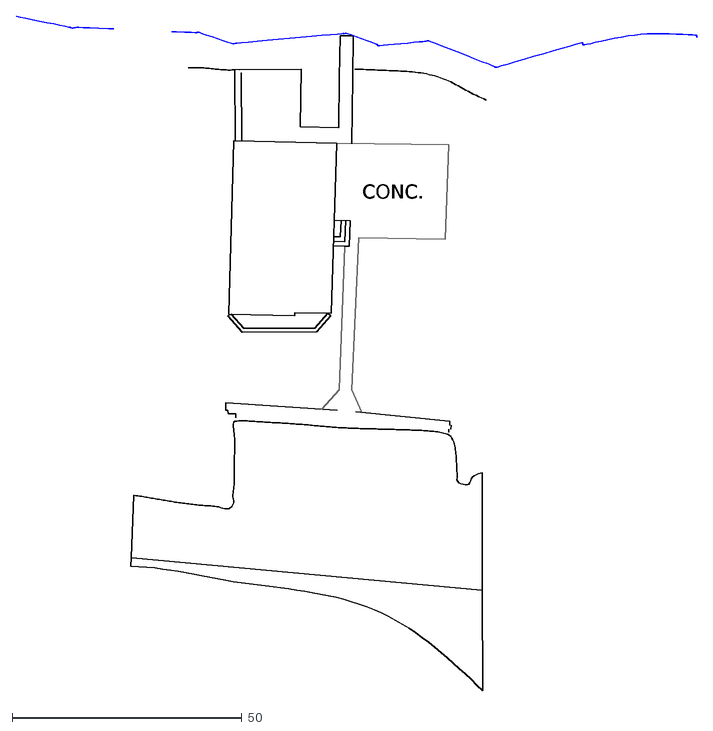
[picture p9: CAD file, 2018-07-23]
Models & CAD/BIM/CAD - Linked/impervious_R12.dxf
CONC.

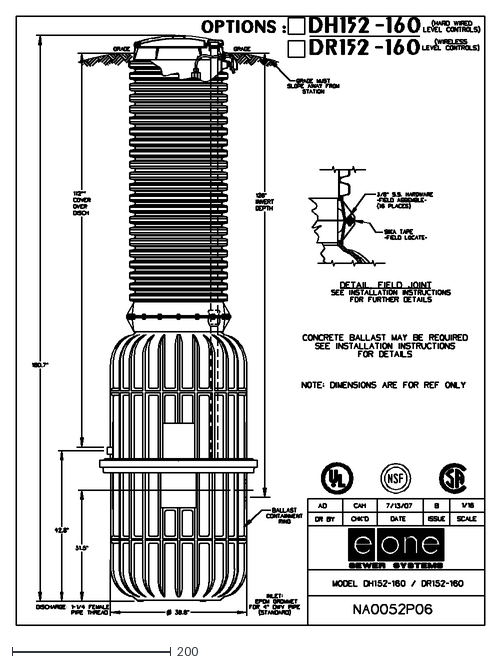
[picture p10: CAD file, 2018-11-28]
Transfer/20181026 - from Sanitary District - Design drawings/dh152.dxf
589.5 x 766.5

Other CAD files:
Research and CA/Research and Submittals/B20 Exterior Vertical Enclosures/B2050 Exterior Doors and Grilles/Door-Inswing-Andersen-400_Series/AW-400_Series-Sections-Inswing_Door.dwg
Research and CA/Research and Submittals/B20 Exterior Vertical Enclosures/B2050 Exterior Doors and Grilles/Garage Doors/overheaddoor.com/416/Track_FrmPdWJm2.dwg
Research and CA/Research and Submittals/B20 Exterior Vertical Enclosures/B2050 Exterior Doors and Grilles/Garage Doors/Wayne Dalton/452/452-aluminum-drawing.dwg
Transfer/20180531 - Survey/aalseth.dwg
Transfer/20180711 - DWG to civil/Survey - Existing Conditions.dwg
Transfer/20181210 - to surveyor/3196 Aalseth Lane-Sheet - A070 - SITE PLAN - TOPOGRAPHY ONLY.dwg
Transfer/20190918 - to lighting designer - backgrounds/3196 Aalseth Lane-Sheet - A200 - BUILDING ELEVATIONS - NORTH-SOUTH.dwg
Models & CAD/BIM/CAD - Linked/impervious.dwg
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

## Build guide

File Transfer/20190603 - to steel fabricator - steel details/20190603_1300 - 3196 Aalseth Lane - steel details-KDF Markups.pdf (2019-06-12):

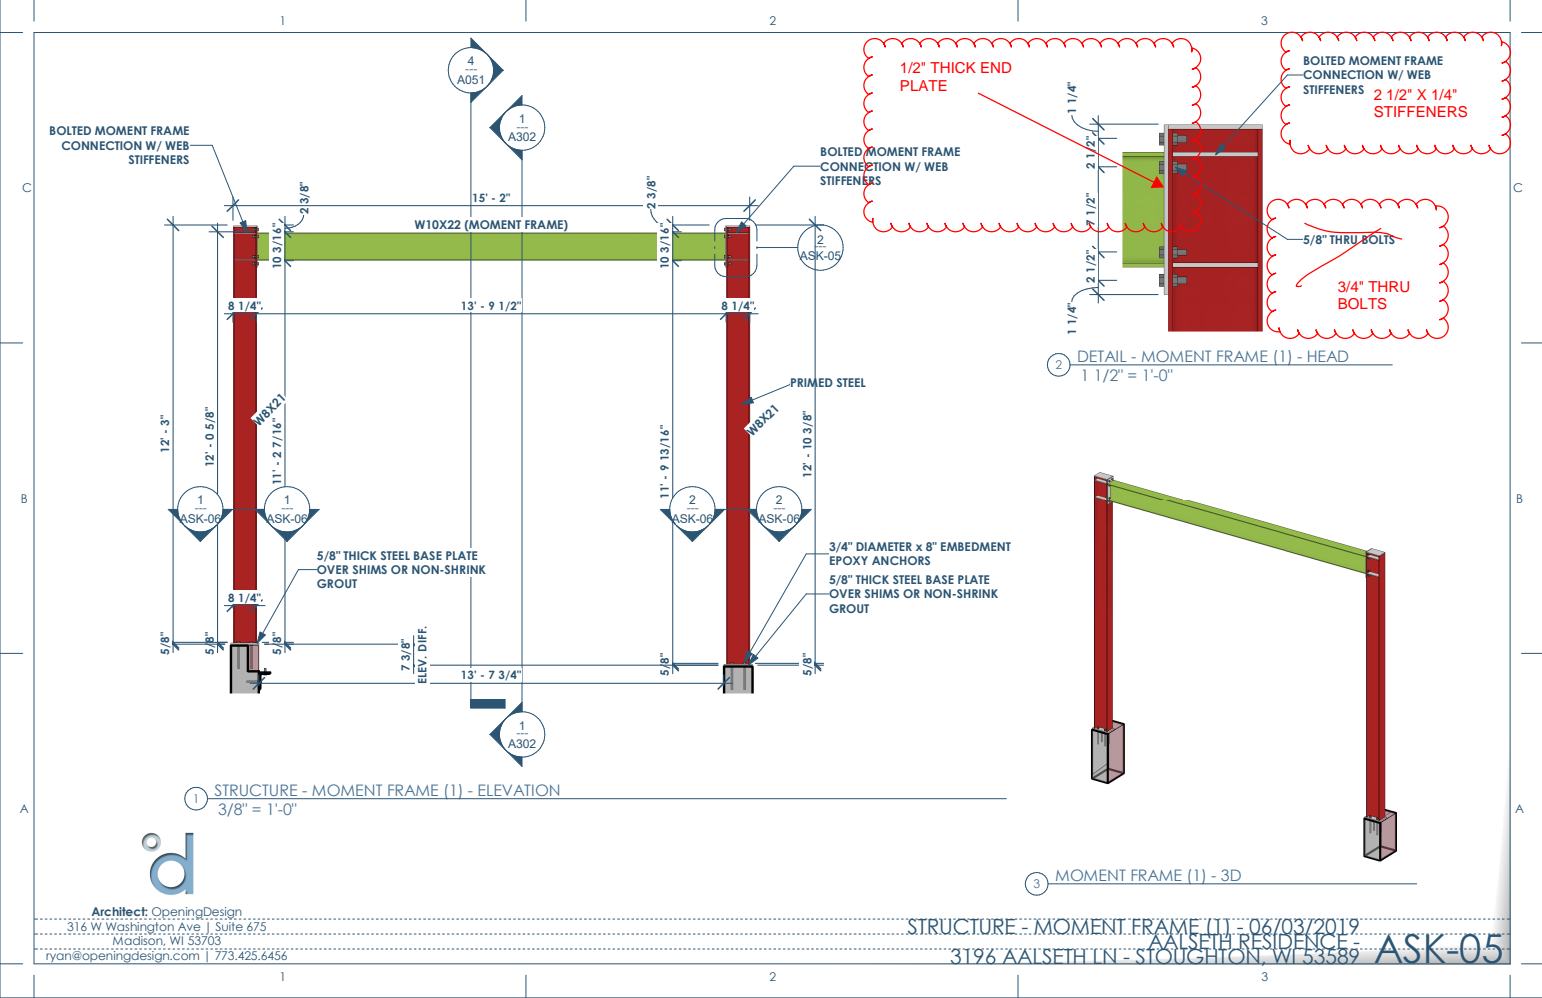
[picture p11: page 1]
PRIMED STEEL; --- ASK-05; W10X22 (MOMENT FRAME); STIFFENERS; ELEV. DIFF.; ASK-06; 5/8" THRU BOLTS; Madison, WI 53703; ryan@openingdesign.com | 773.425.6456; 3196 AALSETH LN - STOUGHTON, WI 53589 AALSETH RESIDENCE - STRUCTURE - MOMENT FRAME (1) - 06/03/2019 ASK-05; MOMENT FRAME (1) - 3D

BOLTED MOMENT FRAME
CONNECTION W/ WEB
STIFFENERS

DETAIL - MOMENT FRAME (1) - HEAD

3/4" DIAMETER x 8" EMBEDMENT
EPOXY ANCHORS
5/8" THICK STEEL BASE PLATE
OVER SHIMS OR NON-SHRINK
GROUT

STRUCTURE - MOMENT FRAME (1) - ELEVATION

Architect: OpeningDesign
316 W Washington Ave | Suite 675

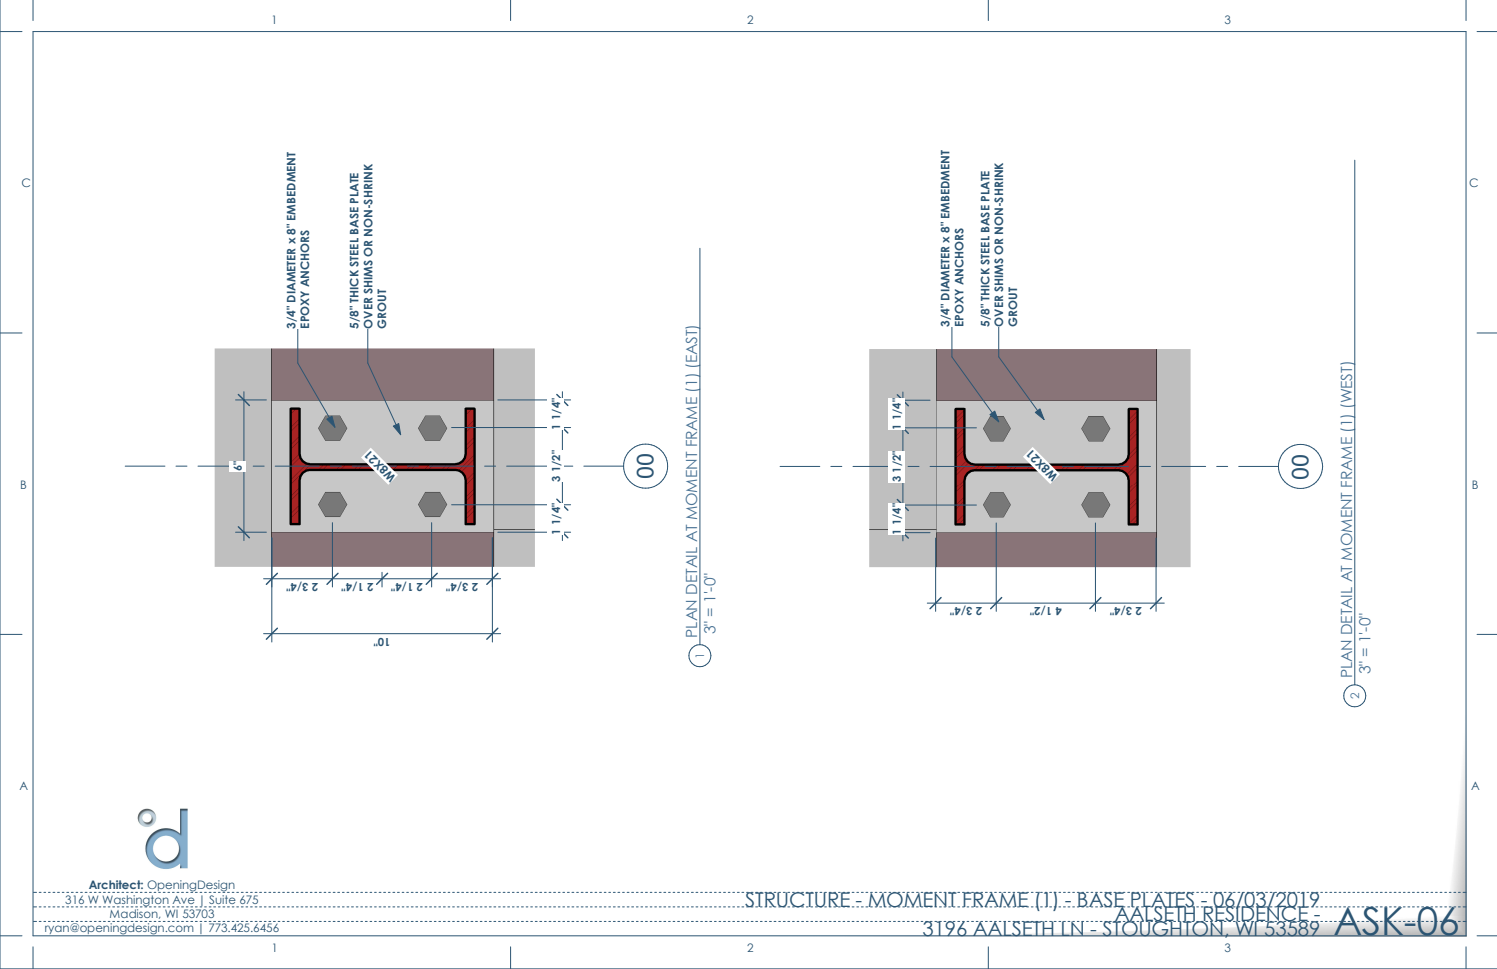
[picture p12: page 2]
3/4" DIAMETER x 8" EMBEDMENT; EPOXY ANCHORS; GROUT; Architect: OpeningDesign; ryan@openingdesign.com | 773.425.6456; 3196 AALSETH LN - STOUGHTON, WI 53589 AALSETH RESIDENCE - STRUCTURE - MOMENT FRAME (1) - BASE PLATES - 06/03/2019; ASK-06

OVER SHIMS OR NON-SHRINK

5/8" THICK STEEL BASE PLATE

1 PLAN DETAIL AT MOMENT FRAME (1) (EAST)

2 PLAN DETAIL AT MOMENT FRAME (1) (WEST)

C | B

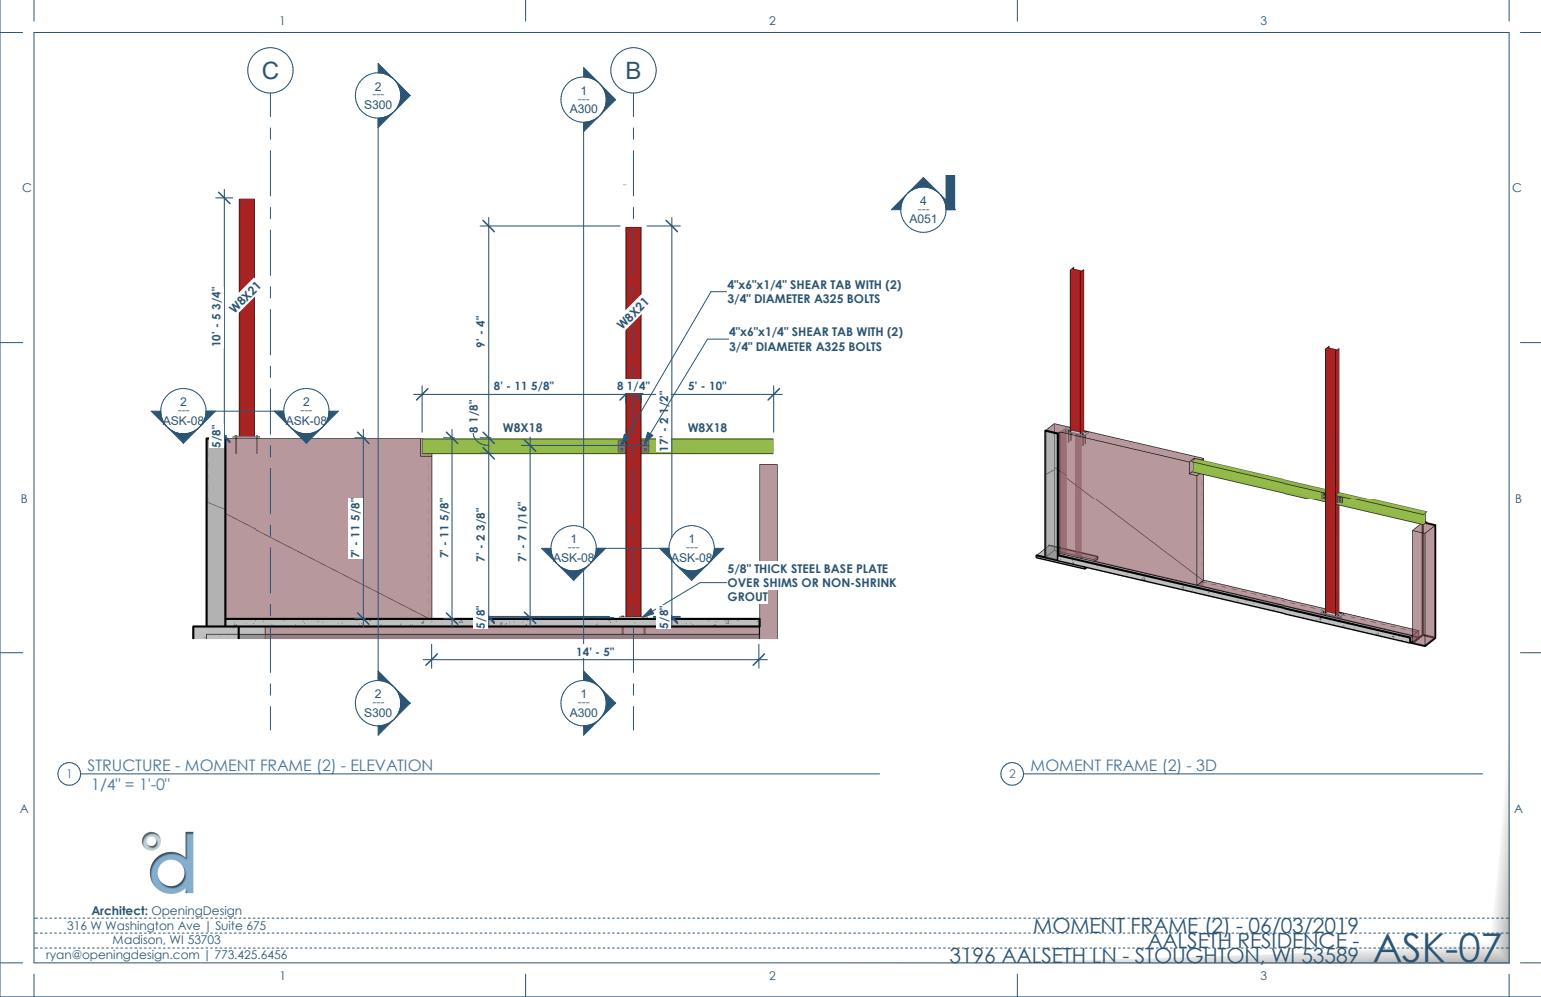
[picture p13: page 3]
ASK-08; Architect: OpeningDesign; ryan@openingdesign.com | 773.425.6456; 3196 AALSETH LN - STOUGHTON, WI 53589 AALSETH RESIDENCE - MOMENT FRAME (2) - 06/03/2019 ASK-07; STRUCTURE - MOMENT FRAME (2) - ELEVATION; MOMENT FRAME (2) - 3D

4"x6"x1/4" SHEAR TAB WITH (2)
3/4" DIAMETER A325 BOLTS

5/8" THICK STEEL BASE PLATE
OVER SHIMS OR NON-SHRINK
GROUT

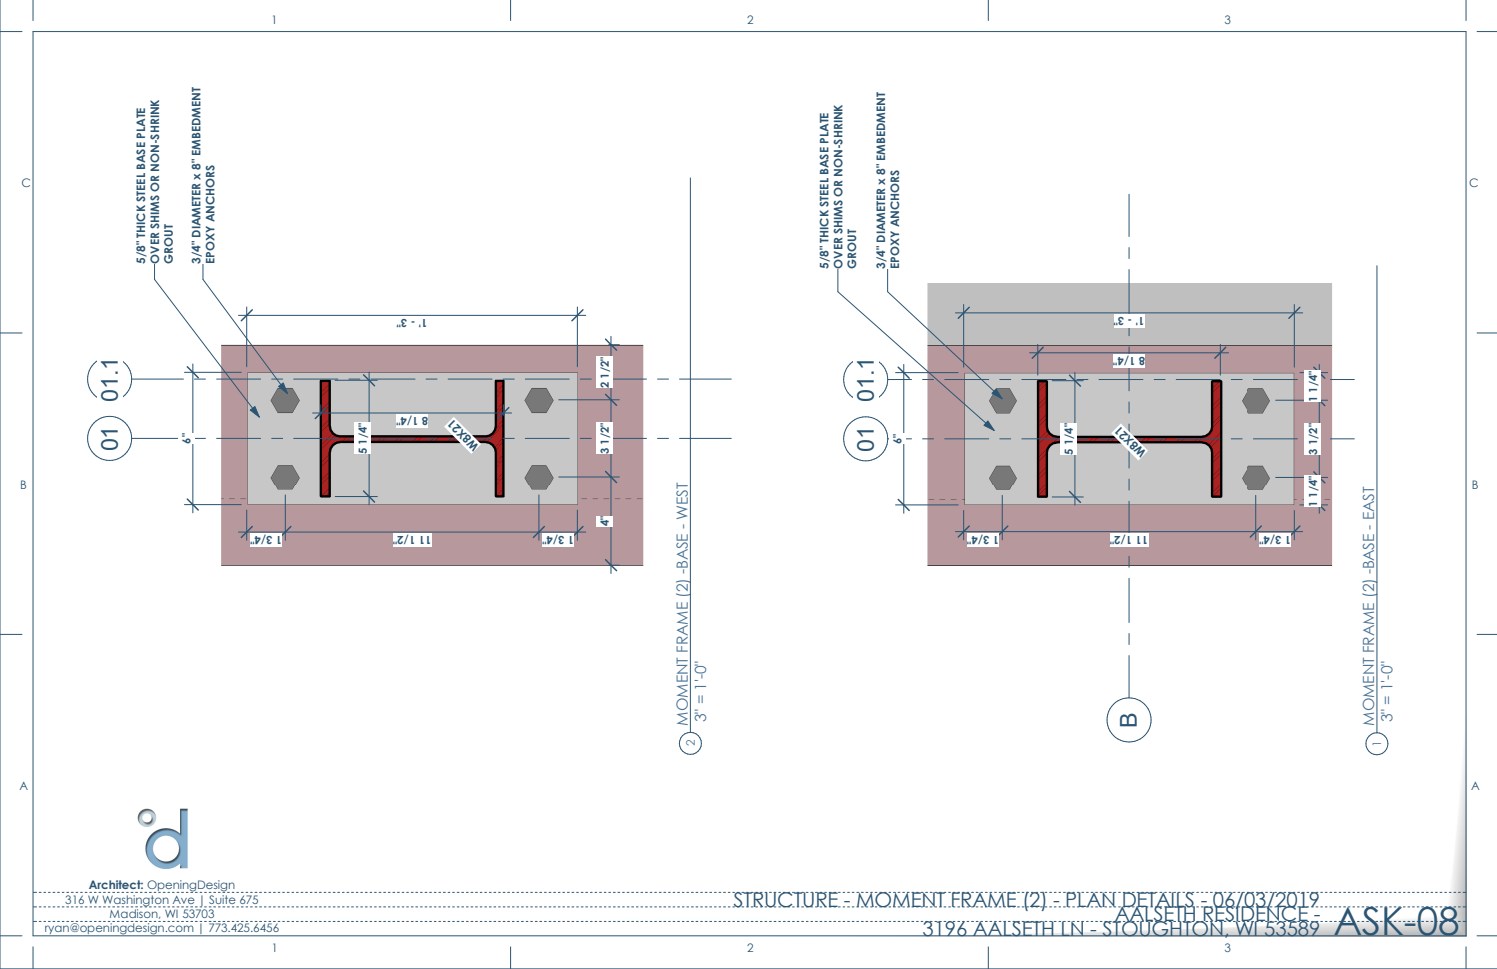
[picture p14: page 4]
3/4" DIAMETER x 8" EMBEDMENT; EPOXY ANCHORS; -SHRINK; GROUT; Architect: OpeningDesign; ryan@openingdesign.com | 773.425.6456; 3196 AALSETH LN - STOUGHTON, WI 53589 AALSETH RESIDENCE - STRUCTURE - MOMENT FRAME (2) - PLAN DETAILS - 06/03/2019; ASK-08

5/8" THICK STEEL BASE PLATE

OVER SHIMS OR NON

2 MOMENT FRAME (2) -BASE - WEST

MOMENT FRAME (2) -BASE - EAST

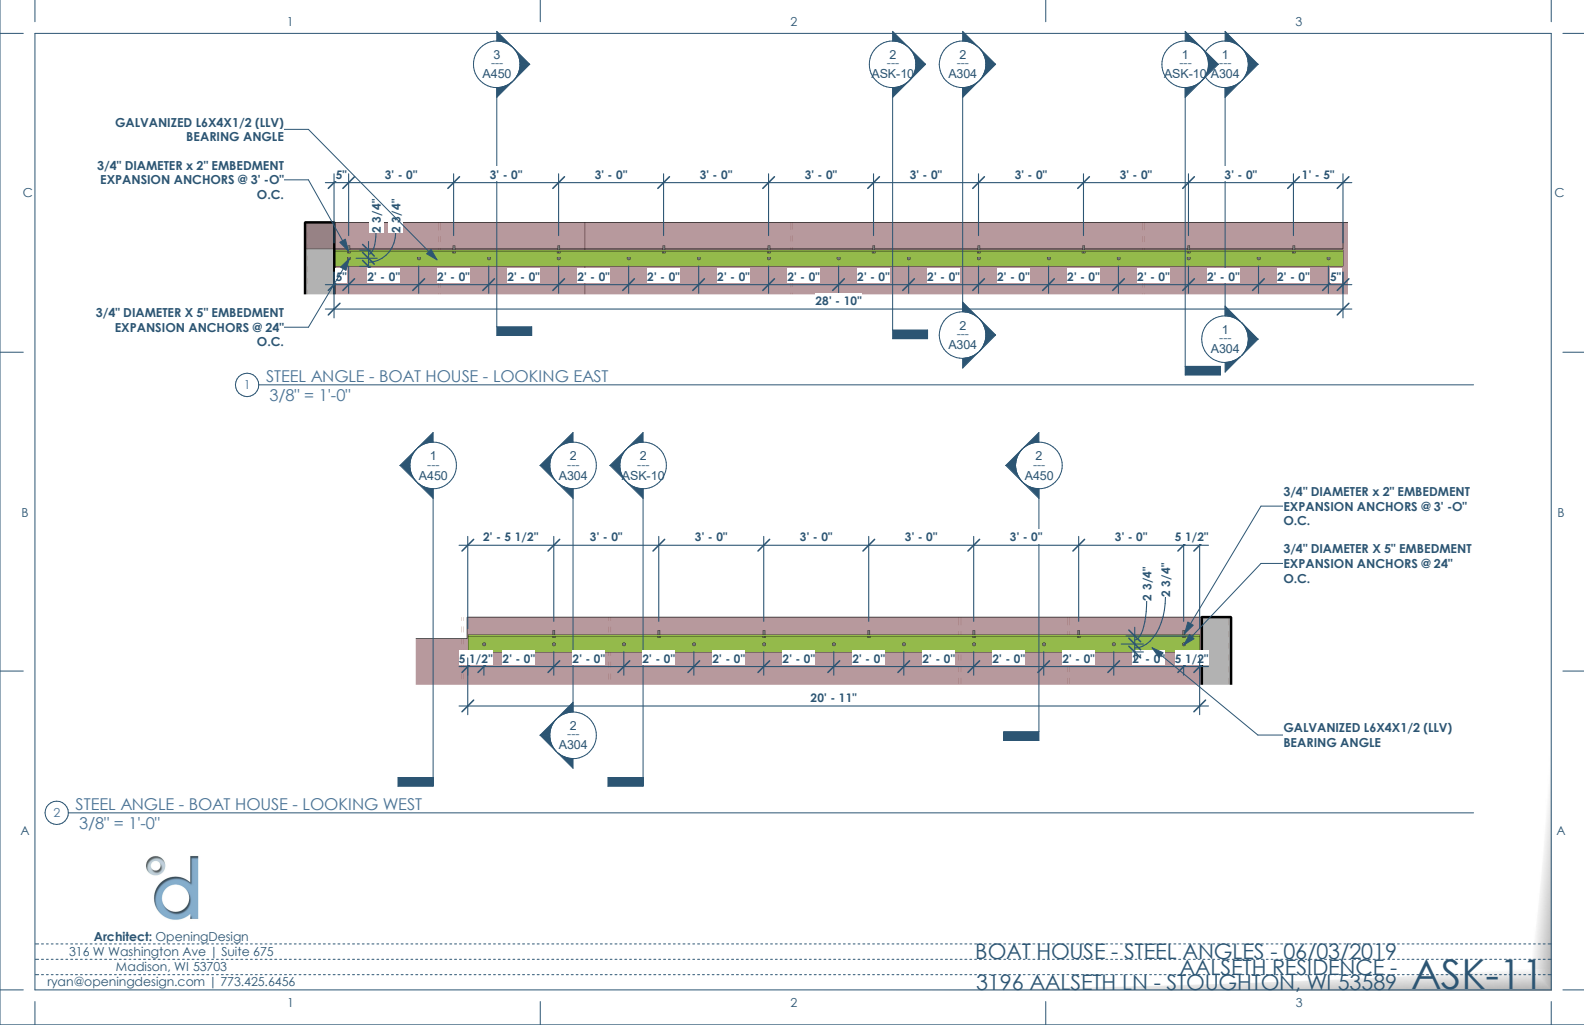
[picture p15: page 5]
ASK-10; 3/4" DIAMETER X 5" EMBEDMENT EXPANSION ANCHORS @ 24" O.C.; 3/4" DIAMETER x 2" EMBEDMENT EXPANSION ANCHORS @ 3' -O" O.C.; GALVANIZED L6X4X1/2 (LLV) BEARING ANGLE; Architect: OpeningDesign; ryan@openingdesign.com | 773.425.6456; 3196 AALSETH LN - STOUGHTON, WI 53589 AALSETH RESIDENCE - BOAT HOUSE - STEEL ANGLES - 06/03/2019 ASK-11

STEEL ANGLE - BOAT HOUSE - LOOKING EAST

STEEL ANGLE - BOAT HOUSE - LOOKING WEST

01.1

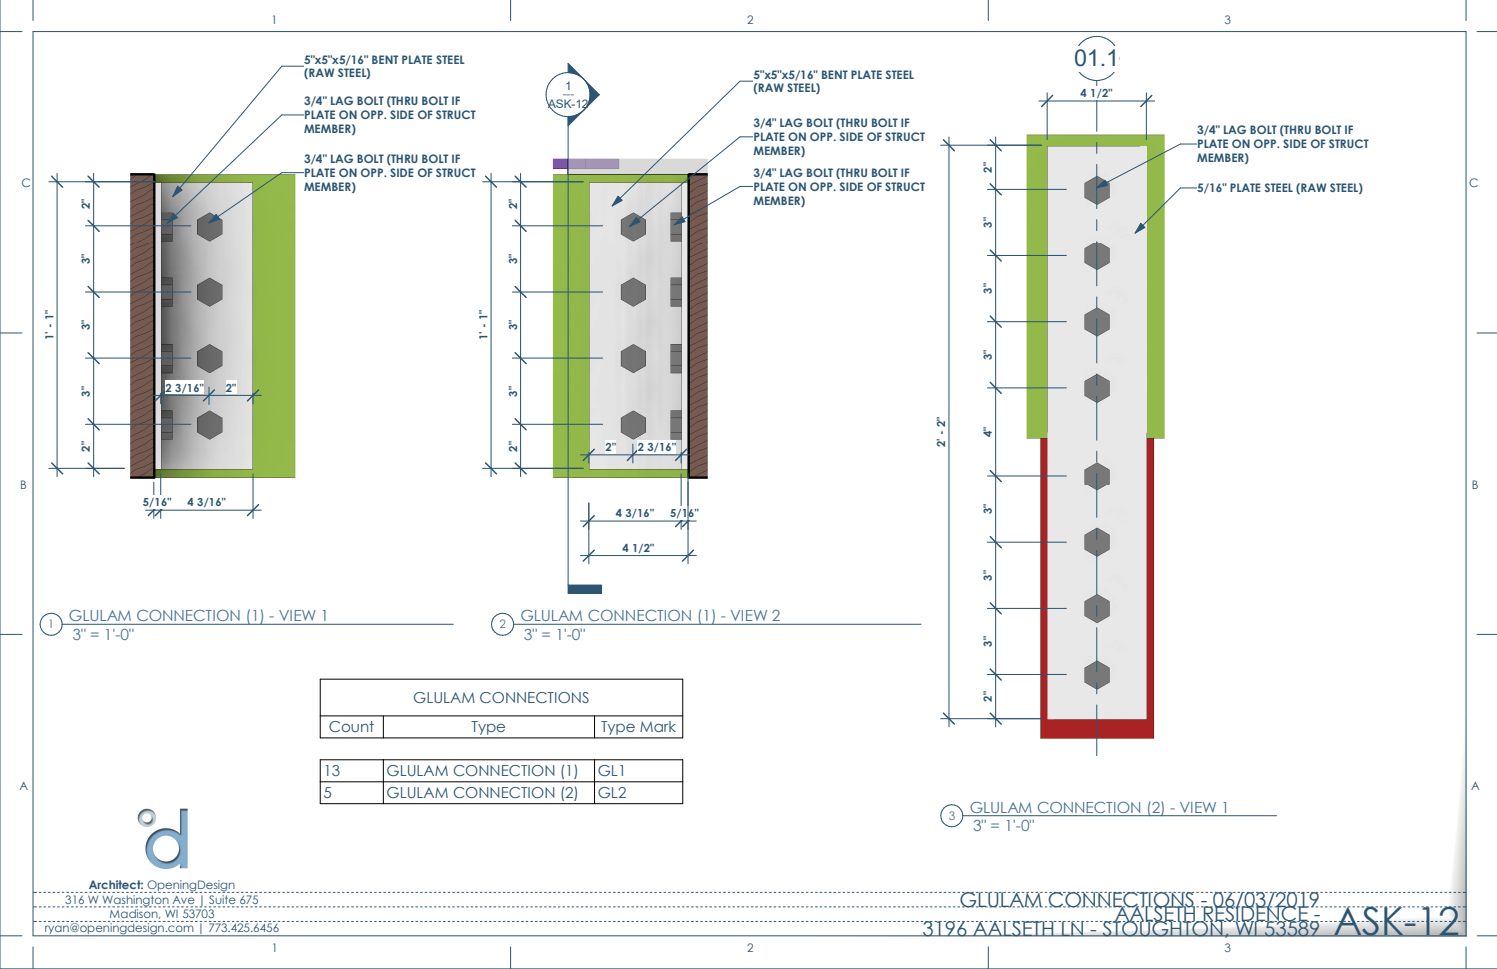
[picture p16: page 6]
(RAW STEEL); ASK-12; Architect: OpeningDesign; ryan@openingdesign.com | 773.425.6456; 3196 AALSETH LN - STOUGHTON, WI 53589 AALSETH RESIDENCE - GLULAM CONNECTIONS - 06/03/2019 ASK-12; GLULAM CONNECTIONS; Count; Type; Type Mark

5"x5"x5/16" BENT PLATE STEEL
(RAW STEEL)

3/4" LAG BOLT (THRU BOLT IF
PLATE ON OPP. SIDE OF STRUCT
MEMBER)

5/16" PLATE STEEL (RAW STEEL)

GLULAM CONNECTION (1) - VIEW 1

GLULAM CONNECTION (1) - VIEW 2

13 | GLULAM CONNECTION (1) | GL1
5 | GLULAM CONNECTION (2) | GL2

GLULAM CONNECTION (2) - VIEW 1

C | B

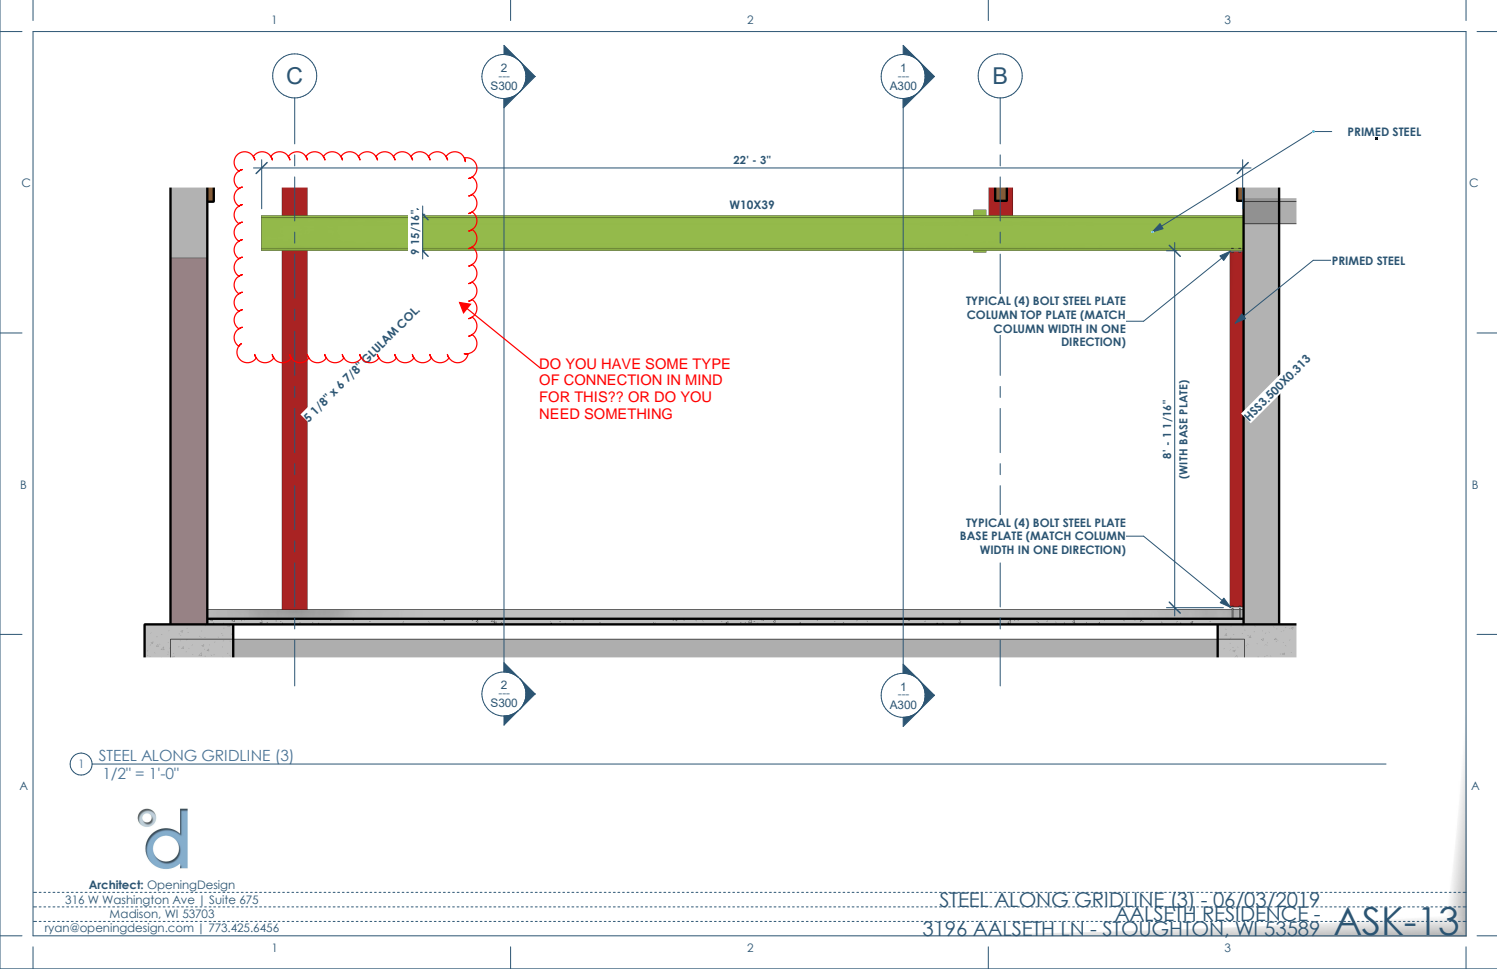
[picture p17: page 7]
PRIMED STEEL; HSS3.500X0.313; 5 1/8" x 6 7/8" GLULAM COL.; DIRECTION); Architect: OpeningDesign; ryan@openingdesign.com | 773.425.6456; 3196 AALSETH LN - STOUGHTON, WI 53589 AALSETH RESIDENCE - STEEL ALONG GRIDLINE (3) - 06/03/2019 ASK-13

TYPICAL (4) BOLT STEEL PLATE
COLUMN TOP PLATE (MATCH
COLUMN WIDTH IN ONE

(WITH BASE PLATE)

BASE PLATE (MATCH COLUMN
WIDTH IN ONE DIRECTION)

STEEL ALONG GRIDLINE (3)

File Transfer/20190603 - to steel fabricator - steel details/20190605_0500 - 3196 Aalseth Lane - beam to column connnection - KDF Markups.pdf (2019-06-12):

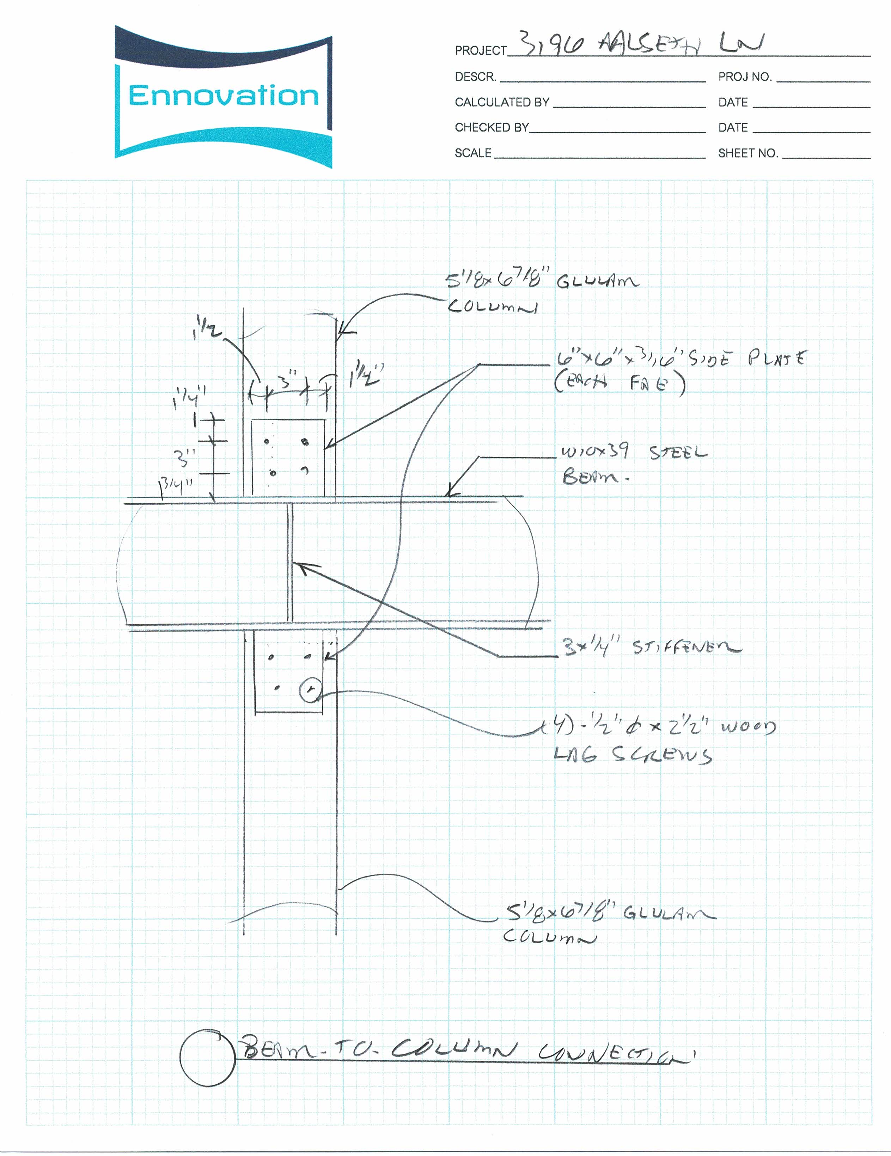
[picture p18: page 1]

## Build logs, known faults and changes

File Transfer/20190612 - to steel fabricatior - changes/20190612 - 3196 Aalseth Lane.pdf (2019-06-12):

# A302 ---¹ A302 --- ⁴ A051 ---

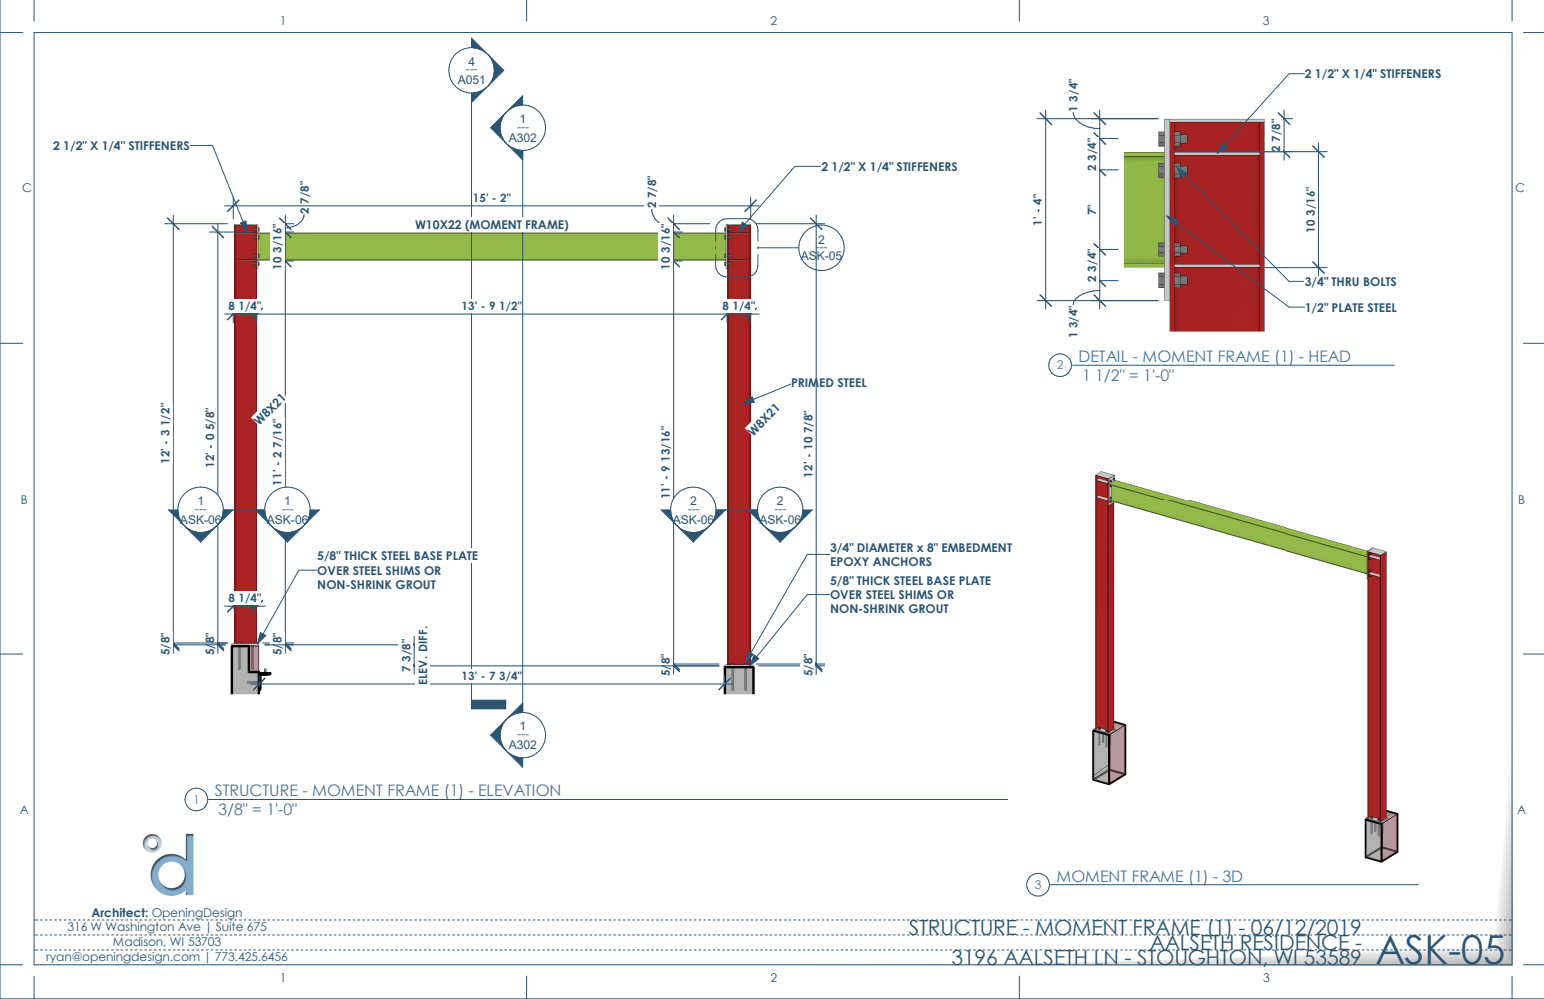
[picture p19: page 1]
PRIMED STEEL; --- ASK-05; W10X22 (MOMENT FRAME); 2 1/2" X 1/4" STIFFENERS; ELEV. DIFF.; ASK-06 --- ¹ ASK-06 ---; 2 ASK-06 --- ² ASK-06 ---; 3/4" DIAMETER x 8" EMBEDMENT; 3/4" THRU BOLTS; 1/2" PLATE STEEL; Madison, WI 53703; ryan@openingdesign.com | 773.425.6456; 3196 AALSETH LN - STOUGHTON, WI 53589 AALSETH RESIDENCE - STRUCTURE - MOMENT FRAME (1) - 06/12/2019 ASK-05; 3 MOMENT FRAME (1) - 3D

1 1/2" = 1'-0" ² DETAIL - MOMENT FRAME (1) - HEAD

5/8" THICK STEEL BASE PLATE
OVER STEEL SHIMS OR
NON-SHRINK GROUT

EPOXY ANCHORS

3/8" = 1'-0" ¹ STRUCTURE - MOMENT FRAME (1) - ELEVATION

Architect: OpeningDesign
316 W Washington Ave | Suite 675

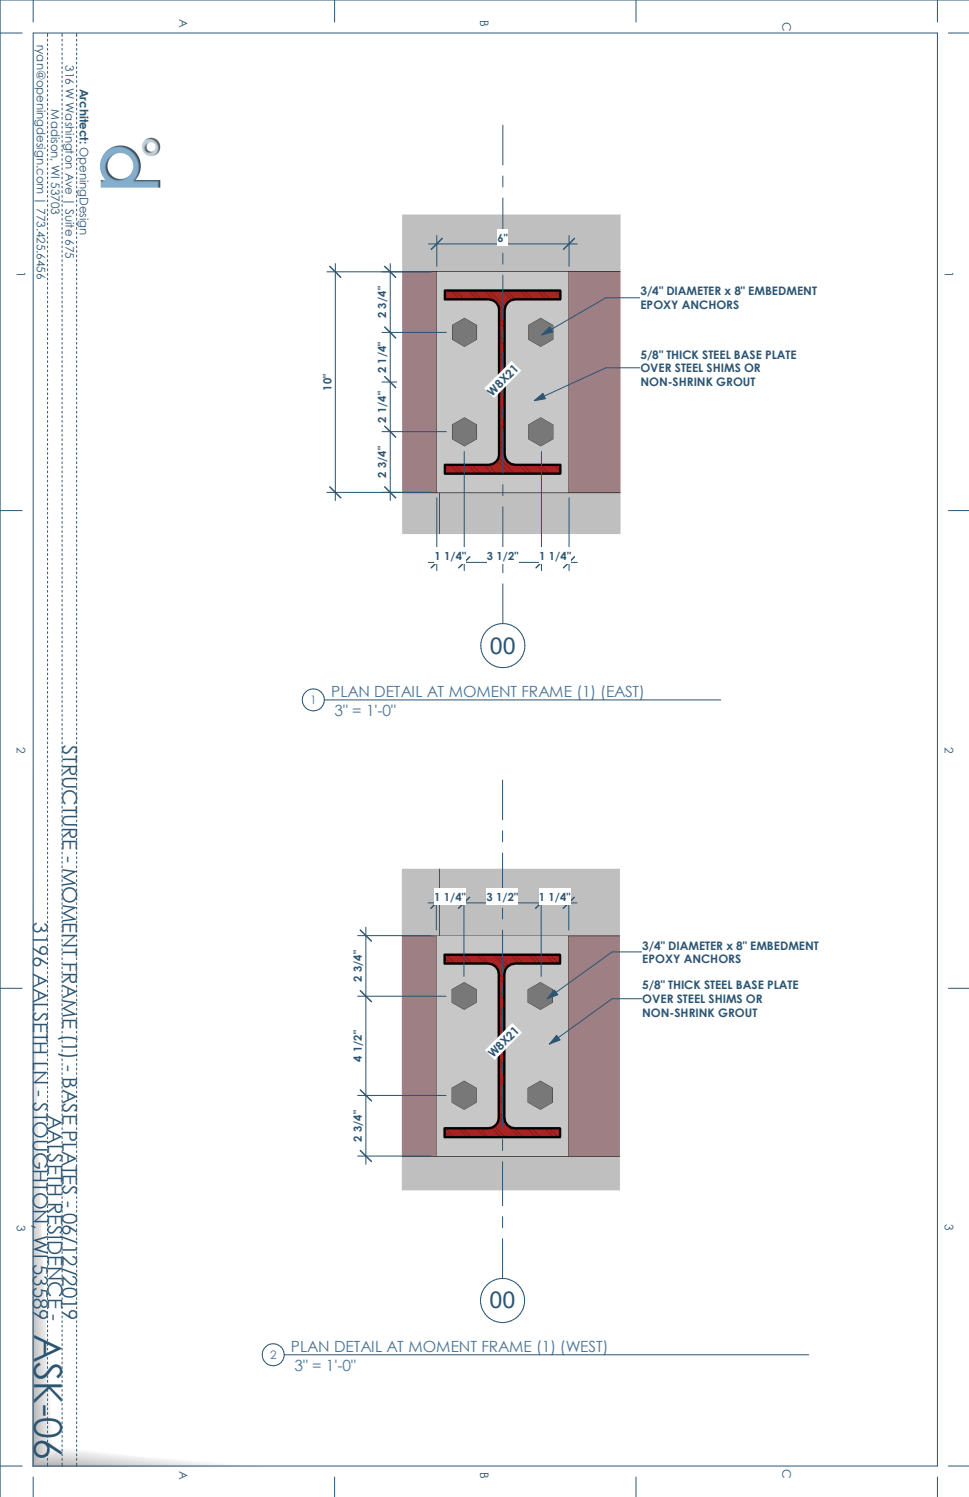
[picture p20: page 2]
3/4" DIAMETER x 8" EMBEDMENT EPOXY ANCHORS; -SHRINK GROUT; Architect: OpeningDesign; Madison, WI 53703

ryan@openingdesign.com | 773.425.6456 3196 AALSETH LN - STOUGHTON, WI 53589 AALSETH RESIDENCE - STRUCTURE - MOMENT FRAME (1) - BASE PLATES - 06/12/2019 ASK-06

316 W Washington Ave | Suite 675

5/8" THICK STEEL BASE PLATE
OVER STEEL SHIMS OR
NON

PLAN DETAIL AT MOMENT FRAME (1) (EAST)

PLAN DETAIL AT MOMENT FRAME (1) (WEST)

C | B

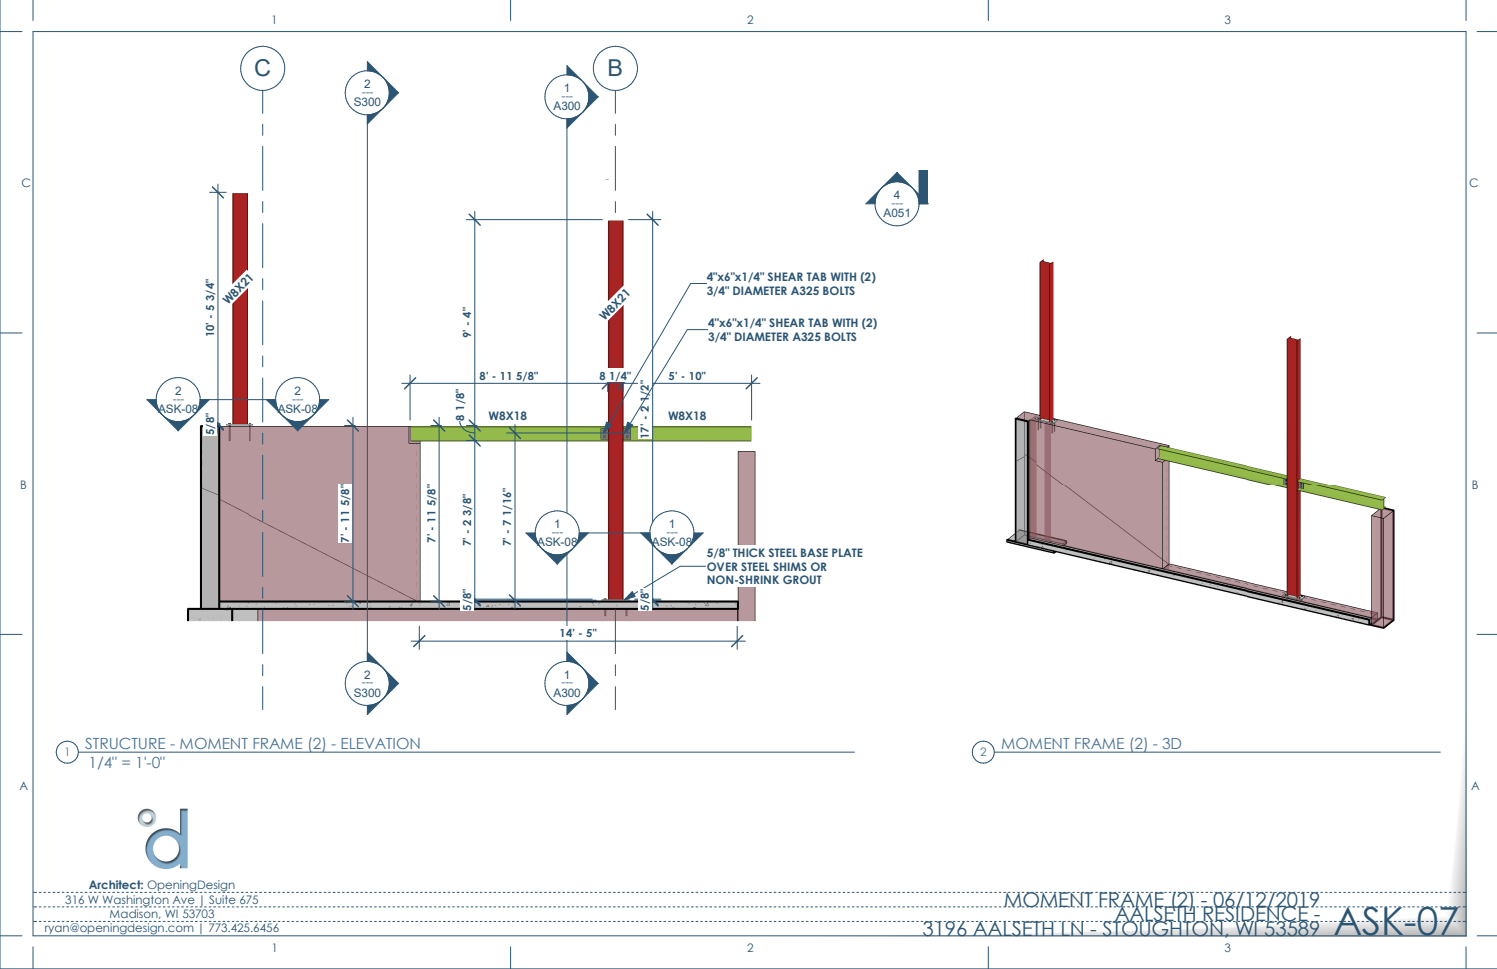
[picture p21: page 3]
5/8" THICK STEEL BASE PLATE OVER STEEL SHIMS OR NON-SHRINK GROUT ⁹' - 4" 8 1/8" 7' - 2 3/8" 5/8"; W⁸X21 W8X18; W8X18 W⁸X21; 4"x6"x1/4" SHEAR TAB WITH (2) 3/4" DIAMETER A325 BOLTS 4"x6"x1/4" SHEAR TAB WITH (2) 3/4" DIAMETER A325 BOLTS 2 ASK-08 ---; 2 ASK-08 ---; 1 ASK-08 --- ¹ ASK-08 --- ¹⁰' - 5 3/4" 5/8"; Architect: OpeningDesign; ryan@openingdesign.com | 773.425.6456; 3196 AALSETH LN - STOUGHTON, WI 53589 AALSETH RESIDENCE - MOMENT FRAME (2) - 06/12/2019 ASK-07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

01 01.1

# " W⁸X21

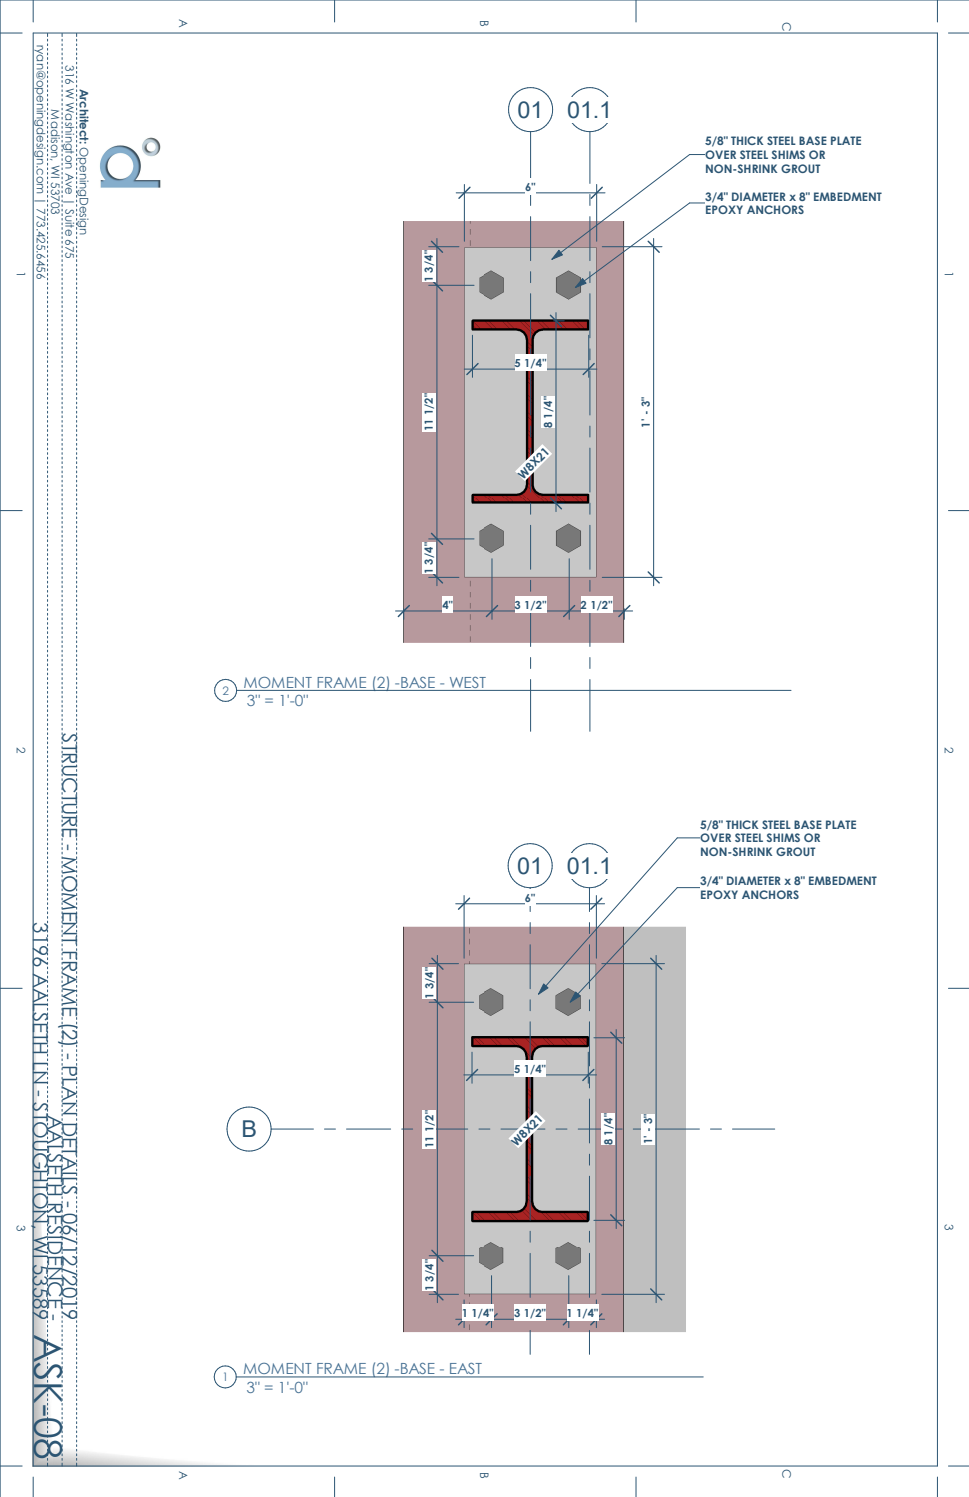
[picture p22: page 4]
3/4" DIAMETER x 8" EMBEDMENT EPOXY ANCHORS; -SHRINK GROUT; " W⁸X21; Architect: OpeningDesign; Madison, WI 53703

ryan@openingdesign.com | 773.425.6456 3196 AALSETH LN - STOUGHTON, WI 53589 AALSETH RESIDENCE - STRUCTURE - MOMENT FRAME (2) - PLAN DETAILS - 06/12/2019 ASK-08

316 W Washington Ave | Suite 675

5/8" THICK STEEL BASE PLATE
OVER STEEL SHIMS OR
NON

2 MOMENT FRAME (2) -BASE - WEST

1 MOMENT FRAME (2) -BASE - EAST

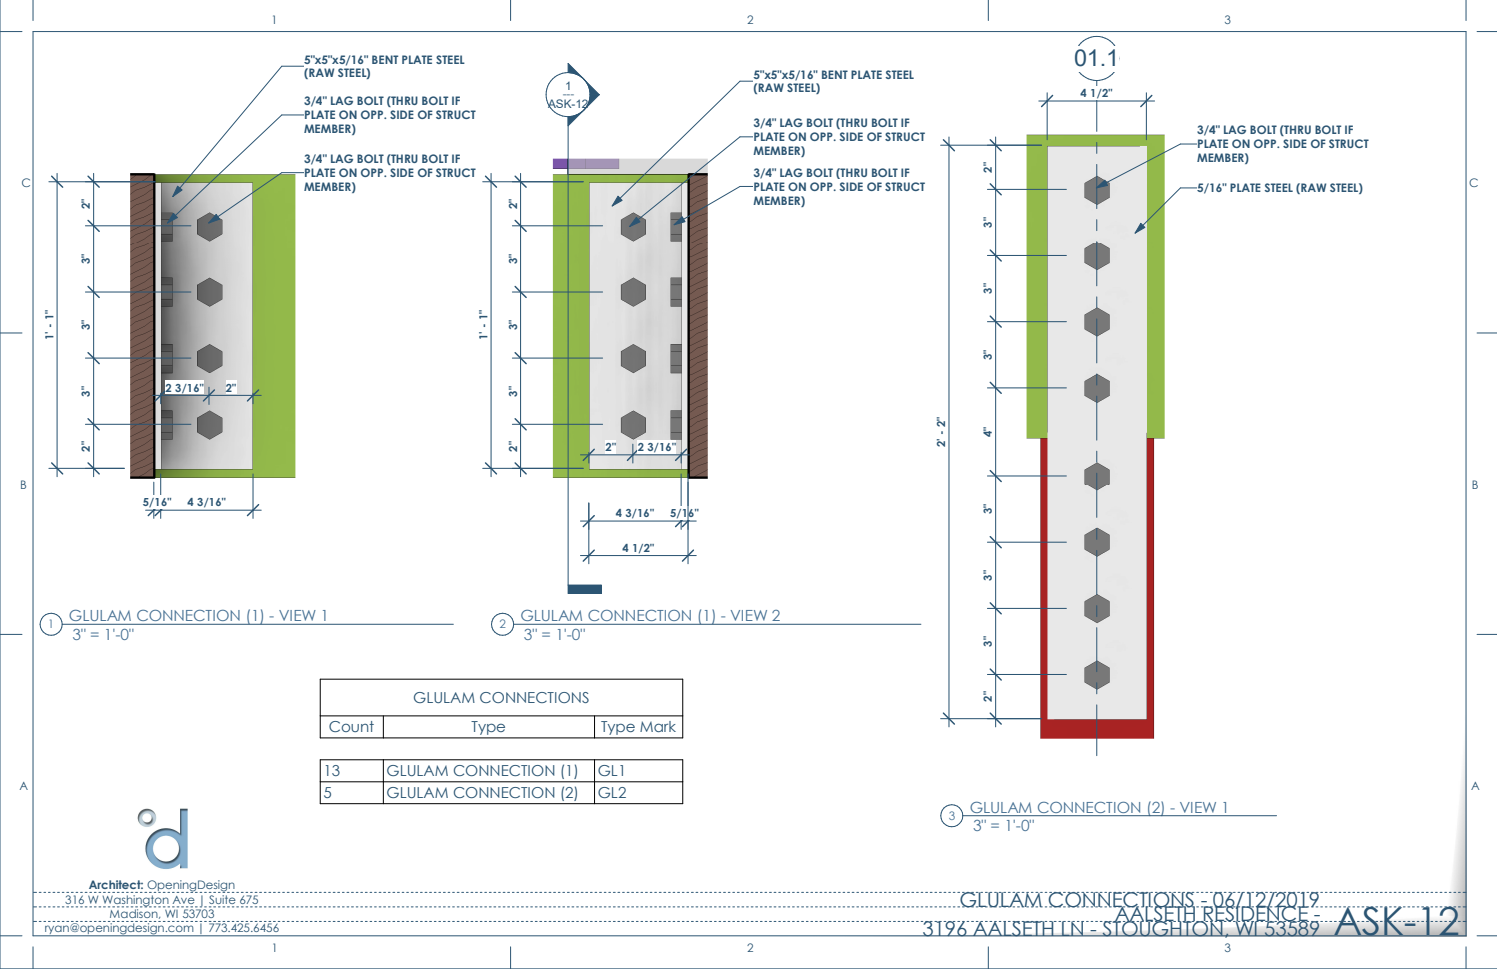
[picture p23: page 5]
(RAW STEEL); ASK-12 ---; Architect: OpeningDesign; ryan@openingdesign.com | 773.425.6456; 3196 AALSETH LN - STOUGHTON, WI 53589 AALSETH RESIDENCE - GLULAM CONNECTIONS - 06/12/2019 ASK-12; 3" = 1'-0" ¹ GLULAM CONNECTION (1) - VIEW 1; 3" = 1'-0" ² GLULAM CONNECTION (1) - VIEW 2; GLULAM CONNECTIONS; Count; Type; Type Mark

5"x5"x5/16" BENT PLATE STEEL
(RAW STEEL)

3/4" LAG BOLT (THRU BOLT IF
PLATE ON OPP. SIDE OF STRUCT
MEMBER)

5/16" PLATE STEEL (RAW STEEL)

13 | GLULAM CONNECTION (1) | GL1
5 | GLULAM CONNECTION (2) | GL2

3" = 1'-0" ³ GLULAM CONNECTION (2) - VIEW 1

C | B

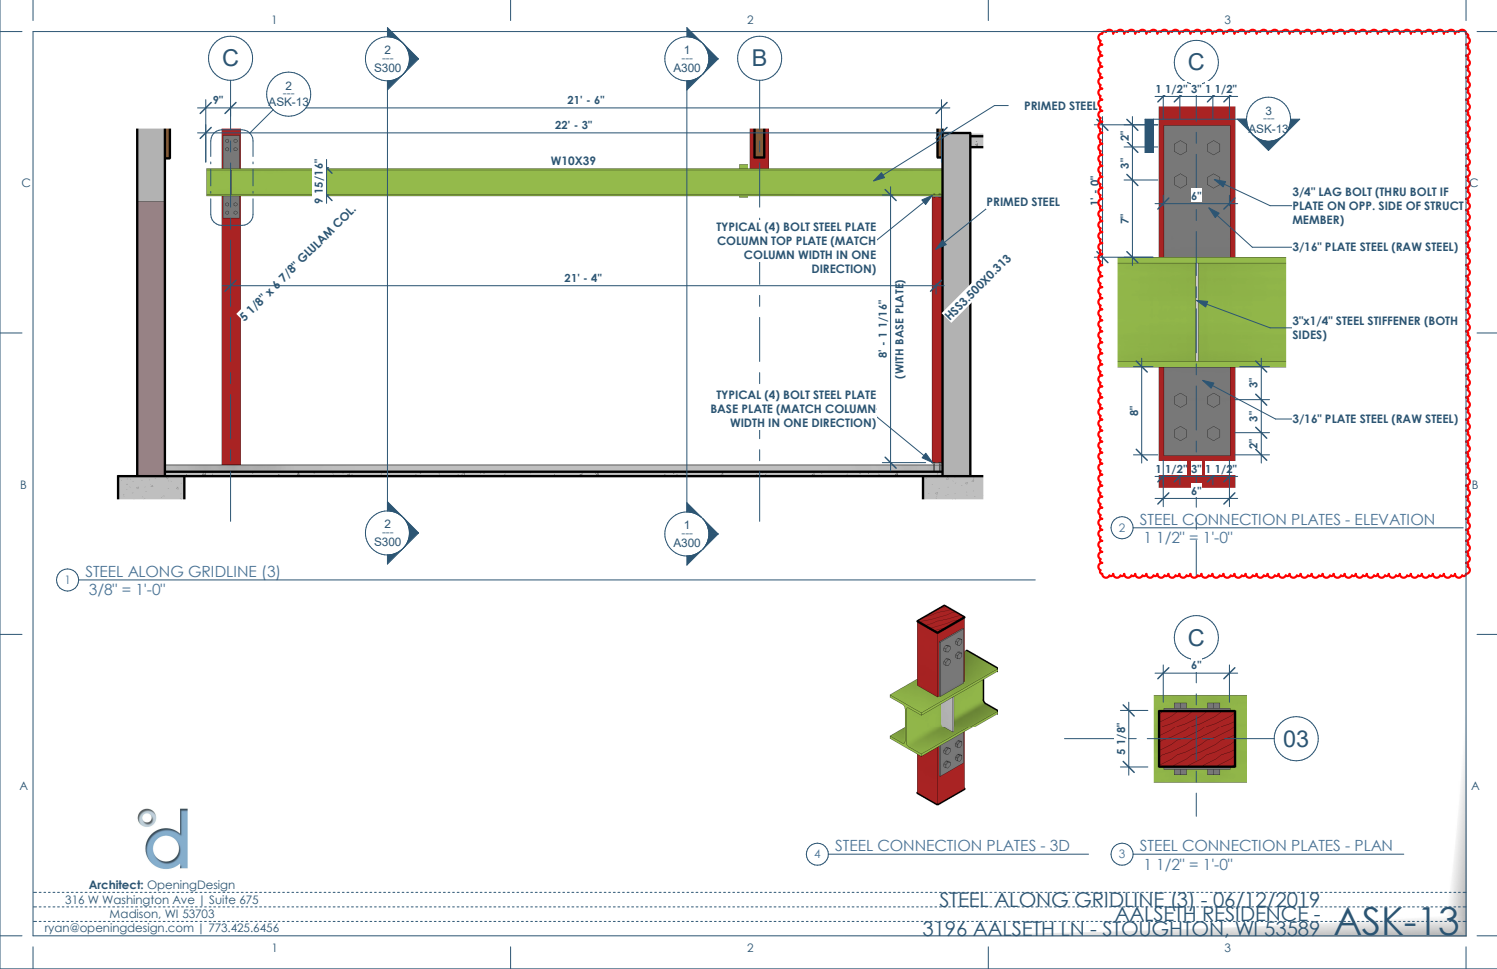
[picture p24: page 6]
(WITH BASE PLATE⁾ 8' - 1 1/16"; PRIMED STEEL HSS3.500X0.313 W10X39 22' - 3" 9 15/16" 5 1/8" x 6 7/8" GLULAM COL.; TYPICAL (4) BOLT STEEL PLATE BASE PLATE (MATCH COLUMN WIDTH IN ONE DIRECTION) TYPICAL (4) BOLT STEEL PLATE COLUMN TOP PLATE (MATCH COLUMN WIDTH IN ONE DIRECTION); PRIMED STEEL 21' - 4" 9"; 21' - 6" --- ASK-13 2; 3 ASK-13 ---; 3/4" LAG BOLT (THRU BOLT IF PLATE ON OPP. SIDE OF STRUCT MEMBER) 3/16" PLATE STEEL (RAW STEEL) ²" 3" 7" 1' - 0"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

1 1/2" = 1'-0" ² STEEL CONNECTION PLATES - ELEVATION

3/8" = 1'-0" ¹ STEEL ALONG GRIDLINE (3)

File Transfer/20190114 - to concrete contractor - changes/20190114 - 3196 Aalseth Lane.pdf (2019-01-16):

2' - 8" - GARAGE -9' - 0" - BOAT HOUSE -7' - 7 3/8" - BASEMENT 0' - 2 3/8" - TOP OF BOAT HOUSE 1' - 6 3/8" - LR -12' - 0" - OHM

| A

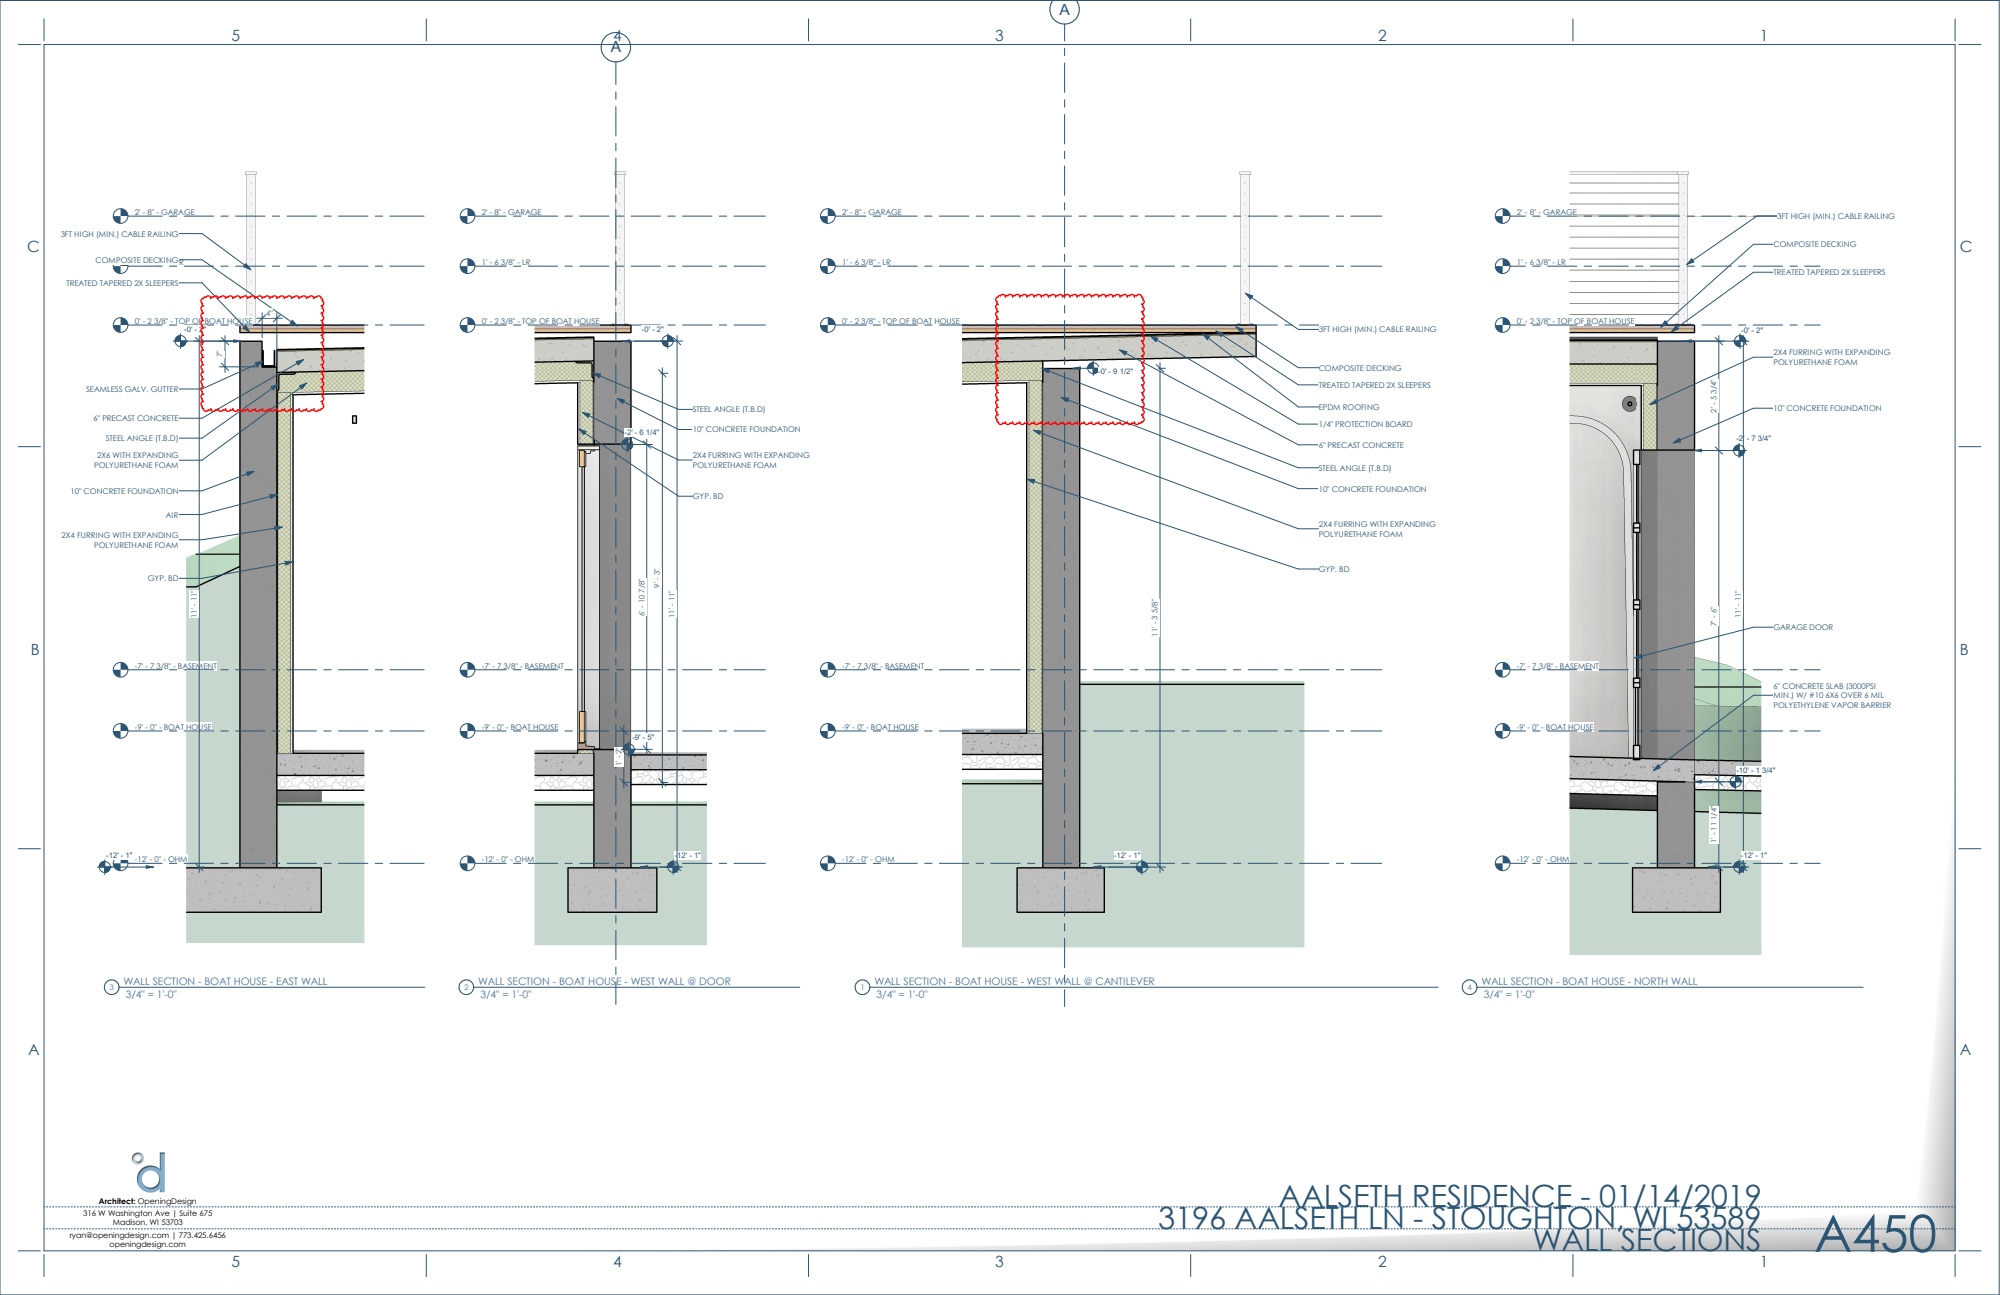
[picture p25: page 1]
6" PRECAST CONCRETE; 10" CONCRETE FOUNDATION; GYP. BD; 1/4" PROTECTION BOARD; EPDM ROOFING; COMPOSITE DECKING; STEEL ANGLE (T.B.D); 2' - 8" - GARAGE -9' - 0" - BOAT HOUSE -7' - 7 3/8" - BASEMENT 0' - 2 3/8" - TOP OF BOAT HOUSE 1' - 6 3/8" - LR -12' - 0" - OHM; GARAGE DOOR; Madison, WI 53703; openingdesign.com; 3/4" = 1'-0" ¹ WALL SECTION - BOAT HOUSE - WEST WALL @ CANTILEVER 3/4" = 1'-0" ² WALL SECTION - BOAT HOUSE - WEST WALL @ DOOR 3/4" = 1'-0" ³ WALL SECTION - BOAT HOUSE - EAST WALL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

2' - 8" - GARAGE -9' - 0" - BOAT HOUSE -7' - 7 3/8" - BASEMENT 0' - 2 3/8" - TOP OF BOAT HOUSE 1' - 6 3/8" - LR -12' - 0" - OHM 2X6 WITH EXPANDING POLYURETHANE FOAM 10" CONCRETE FOUNDATIONAIR 2X4 FURRING WITH EXPANDING POLYURETHANE FOAM GYP. BD 6" PRECAST CONCRETE SEAMLESS GALV. GUTTER TREATED TAPERED 2X SLEEPERS COMPOSITE DECKING 3FT HIGH (MIN.) CABLE RAILING -0' - 2" -12' - 1"

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

3FT HIGH (MIN.) CABLE RAILING

TREATED TAPERED 2X SLEEPERS

2X4 FURRING WITH EXPANDING
POLYURETHANE FOAM

6" CONCRETE SLAB (3000PSI
MIN.) W/ #10 6X6 OVER 6 MIL
POLYETHYLENE VAPOR BARRIER

A450 ³¹⁹⁶ AALSETH LN - STOUGHTON, WI 53589 WALL SECTIONS AALSETH RESIDENCE - 01/14/2019

Architect: OpeningDesign
316 W Washington Ave | Suite 675

ryan@openingdesign.com | 773.425.6456

02

03

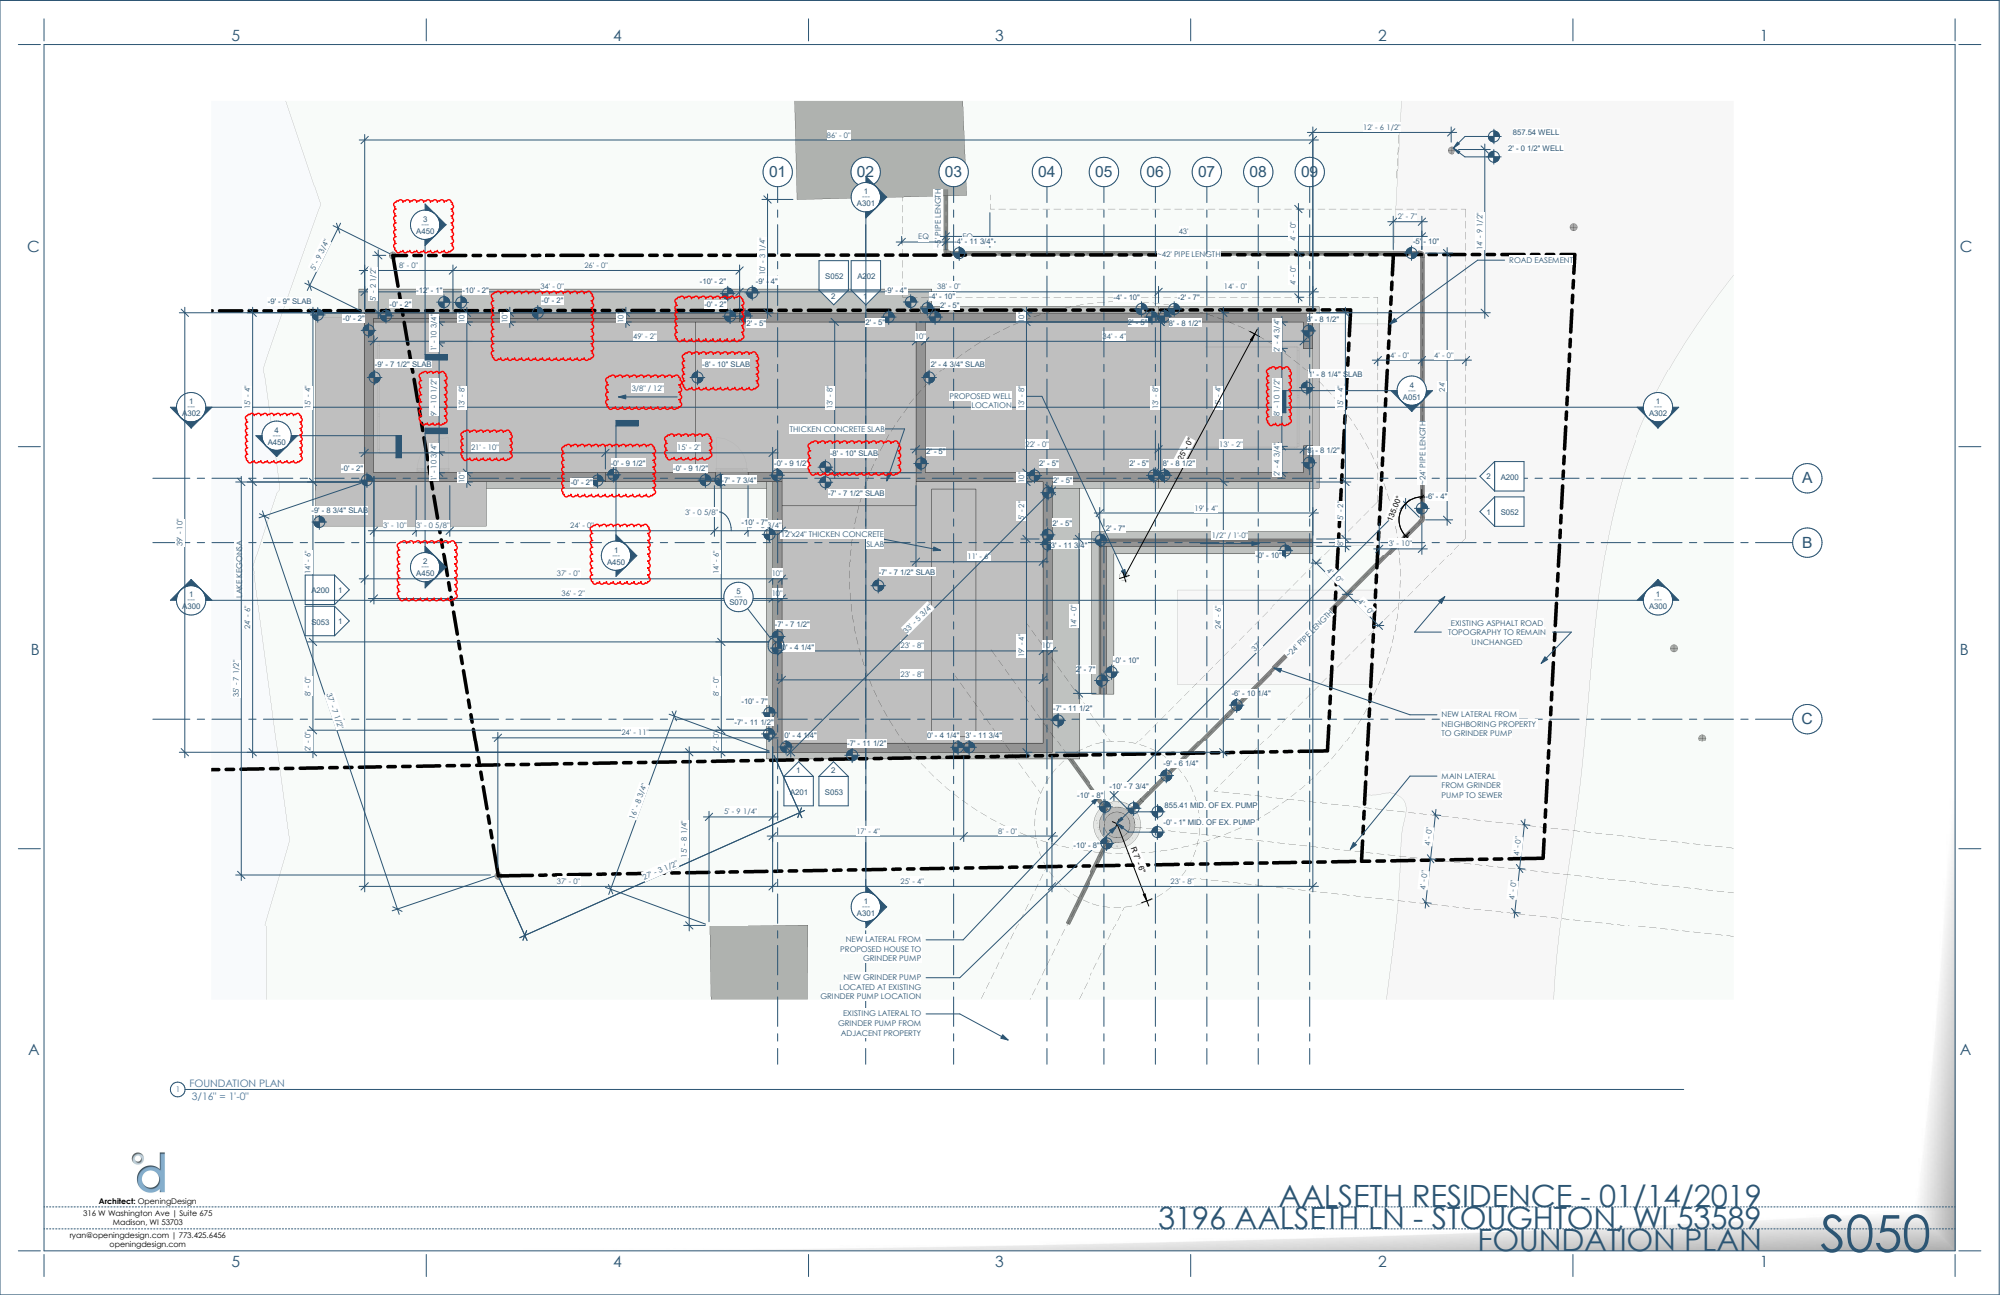
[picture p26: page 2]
~42' PIPE LENGTH; ~24' PIPE LENGTH; ~5' PIPE LENGTH; GRINDER PUMP; PROPOSED WELL LOCATION; LAKE KEGONSA; ROAD EASEMENT; UNCHANGED; -9' - 8 3/4" SLAB; -9' - 9" SLAB; 1' - 8 1/4" SLAB; -9' - 7 1/2" SLAB; -8' - 10" SLAB; 2' - 4 3/4" SLAB; -7' - 7 1/2" SLAB; 12"x24" THICKEN CONCRETE SLAB; 2' - 0 1/2" WELL; 857.54 WELL; 855.41 MID.; OF EX. PUMP; 3/16" = 1'-0" ¹ FOUNDATION PLAN

THICKEN CONCRETE SLAB

EXISTING ASPHALT ROAD
TOPOGRAPHY TO REMAIN

NEW LATERAL FROM
NEIGHBORING PROPERTY
TO GRINDER PUMP

MAIN LATERAL
FROM GRINDER
PUMP TO SEWER

-0' - 1" MID. OF EX. PUMP

PROPOSED HOUSE TO

NEW GRINDER PUMP
LOCATED AT EXISTING
GRINDER PUMP LOCATION

EXISTING LATERAL TO
GRINDER PUMP FROM
ADJACENT PROPERTY

S050 ³¹⁹⁶ AALSETH LN - STOUGHTON, WI 53589 FOUNDATION PLAN AALSETH RESIDENCE - 01/14/2019

A | B | C

A300 ---1

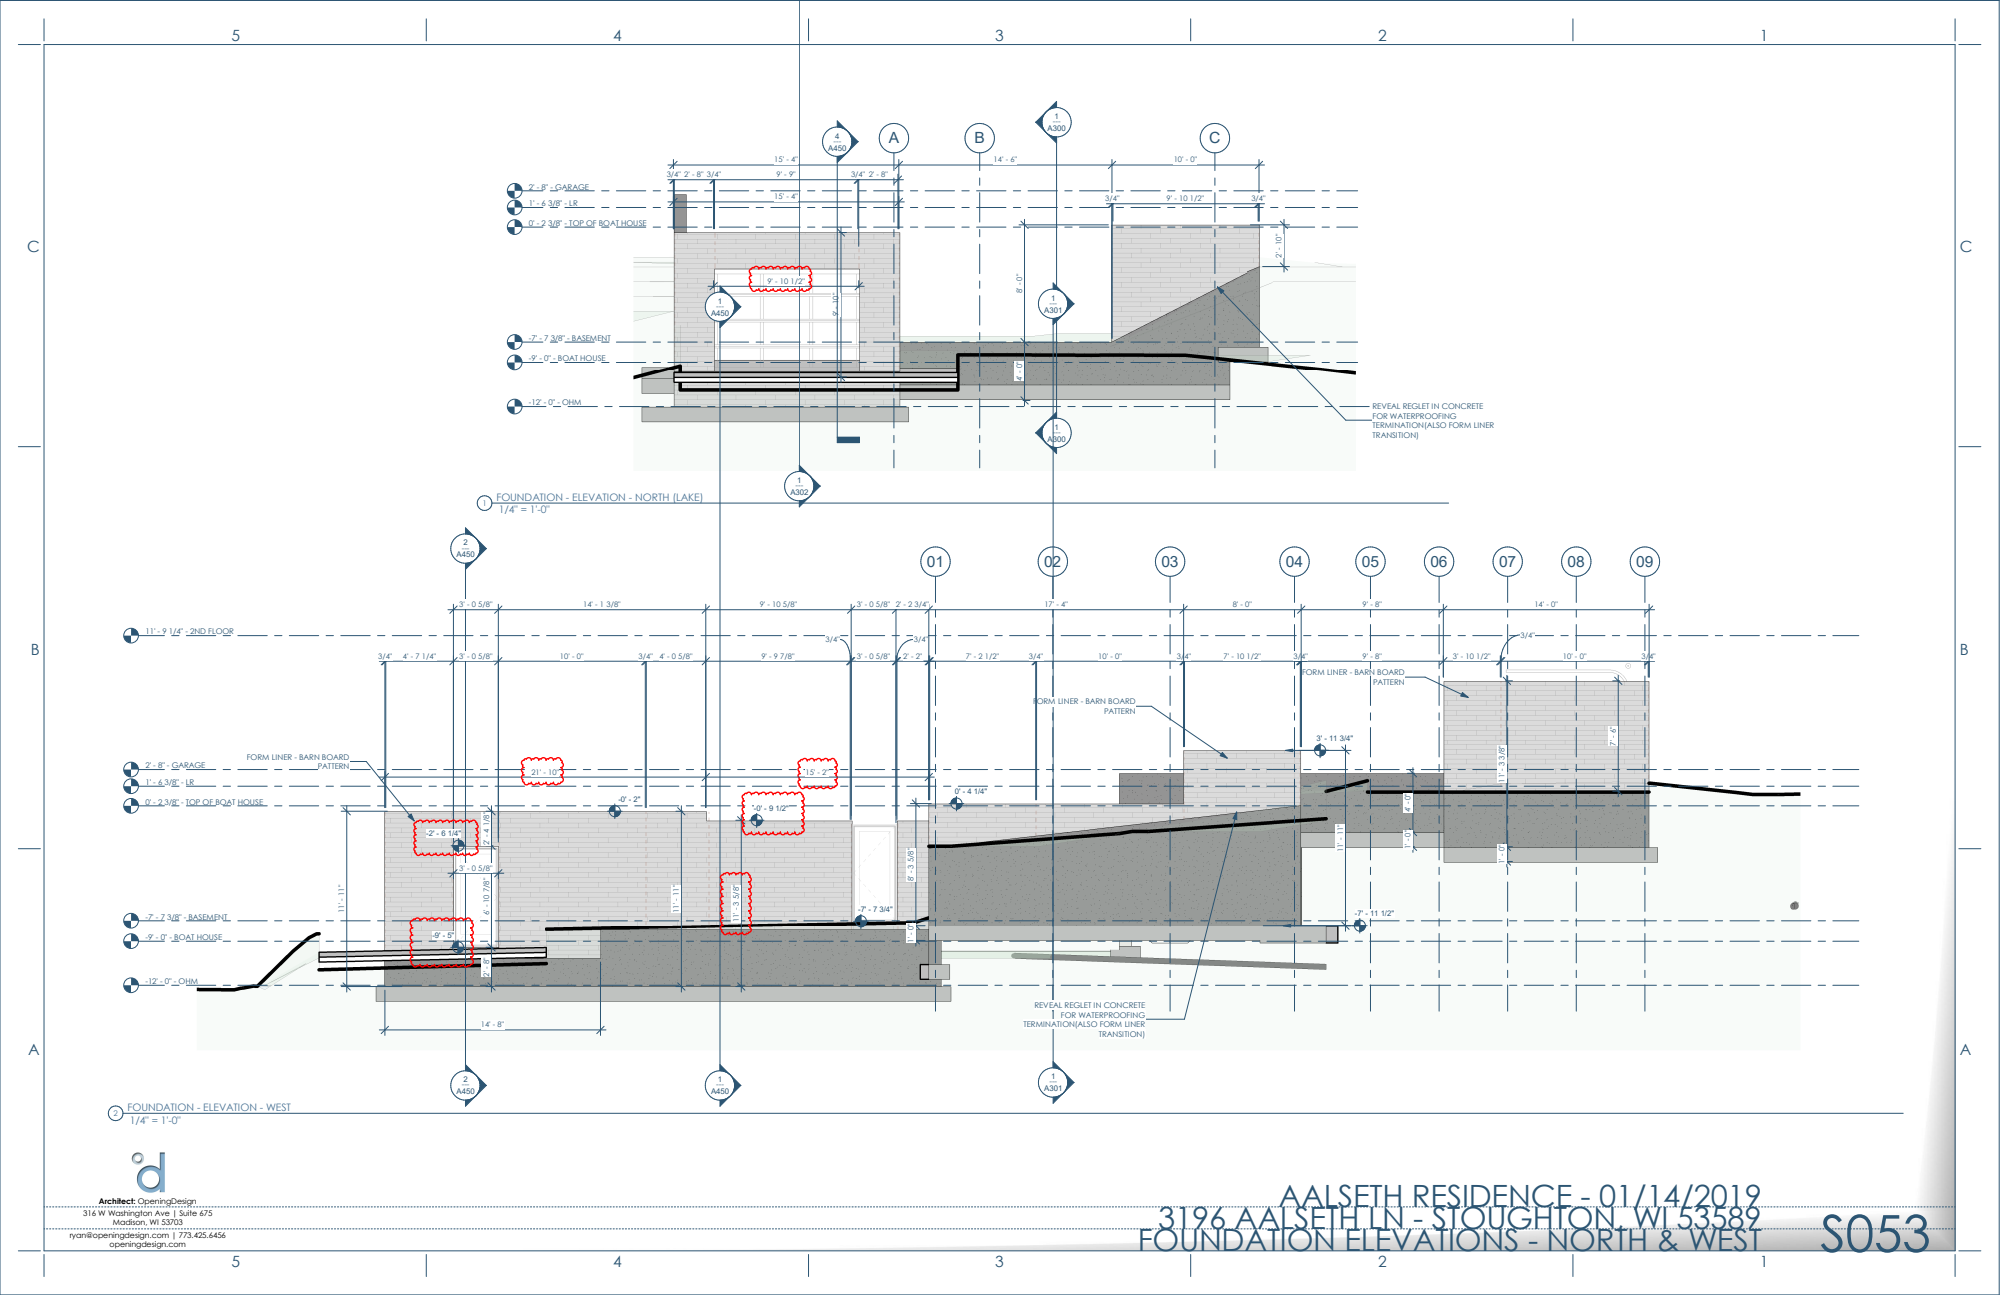
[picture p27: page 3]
2' - 8" - GARAGE; PATTERN; FOR WATERPROOFING; TRANSITION)

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

REVEAL REGLET IN CONCRETE
FOR WATERPROOFING
TERMINATION(ALSO FORM LINER
TRANSITION)

1/4" = 1'-0" ¹ FOUNDATION - ELEVATION - NORTH (LAKE)
11' - 9 1/4" - 2ND FLOOR -9' - 0" - BOAT HOUSE -7' - 7 3/8" - BASEMENT 0' - 2 3/8" - TOP OF BOAT HOUSE 1' - 6 3/8" - LR -12' - 0" - OHM

FORM LINER - BARN BOARD

1/4" = 1'-0" ² FOUNDATION - ELEVATION - WEST

S053 ³¹⁹⁶ AALSETH LN - STOUGHTON, WI 53589 FOUNDATION ELEVATIONS - NORTH & WEST AALSETH RESIDENCE - 01/14/2019

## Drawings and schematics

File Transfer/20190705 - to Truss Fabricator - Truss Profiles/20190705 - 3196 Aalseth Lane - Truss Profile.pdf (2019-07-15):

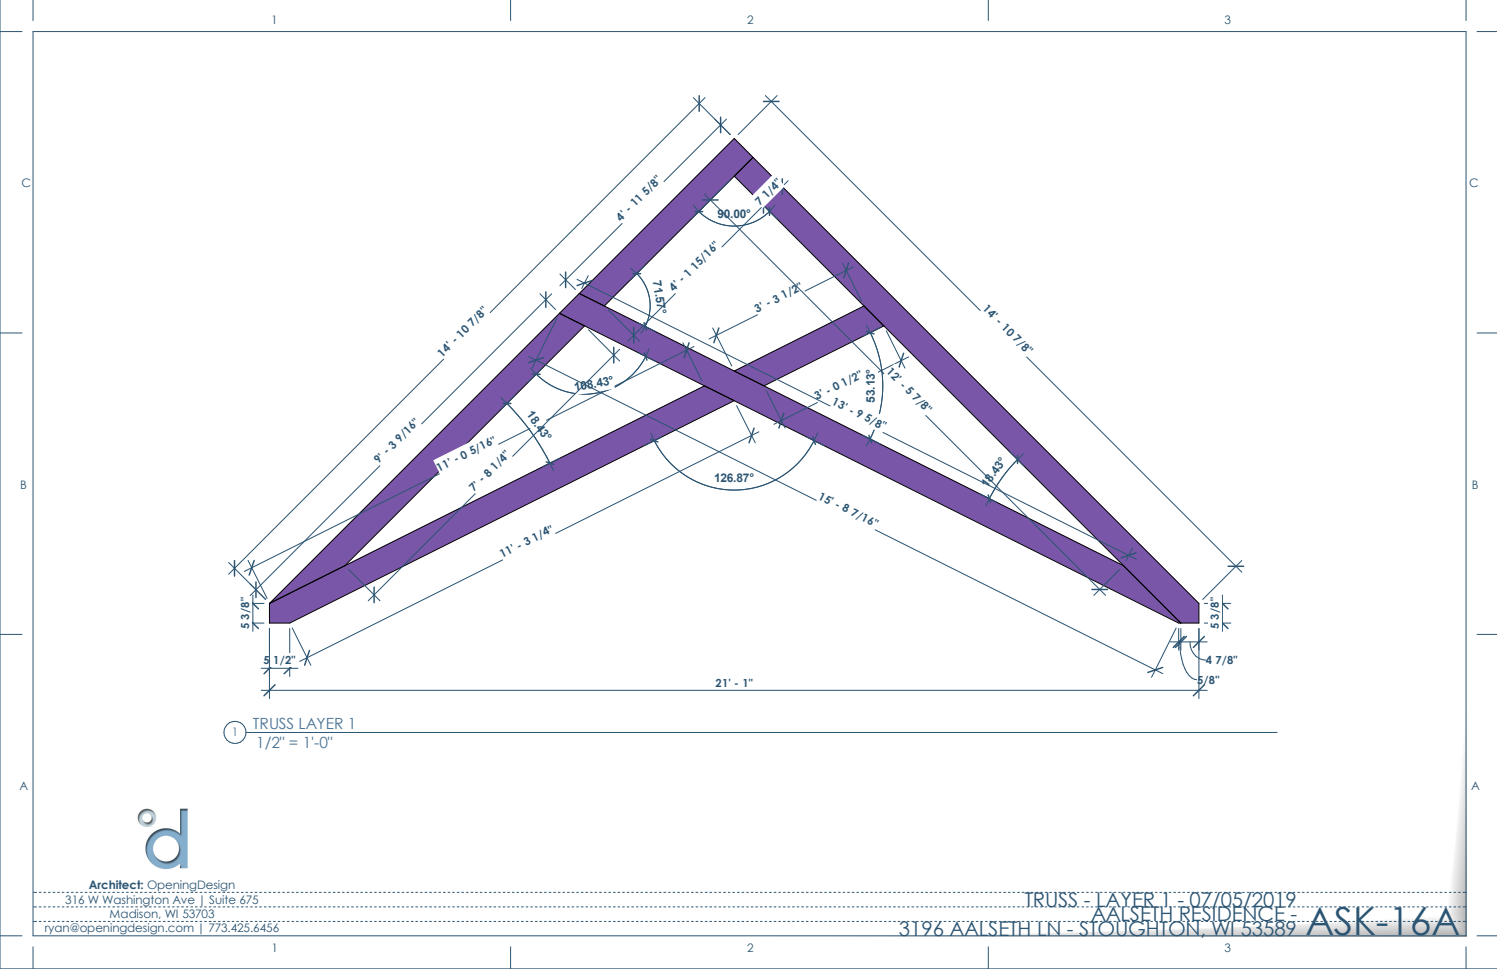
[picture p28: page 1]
Madison, WI 53703; ryan@openingdesign.com | 773.425.6456; 3196 AALSETH LN - STOUGHTON, WI 53589 AALSETH RESIDENCE - TRUSS - LAYER 1 - 07/05/2019 ASK-16A; TRUSS LAYER 1

Architect: OpeningDesign
316 W Washington Ave | Suite 675

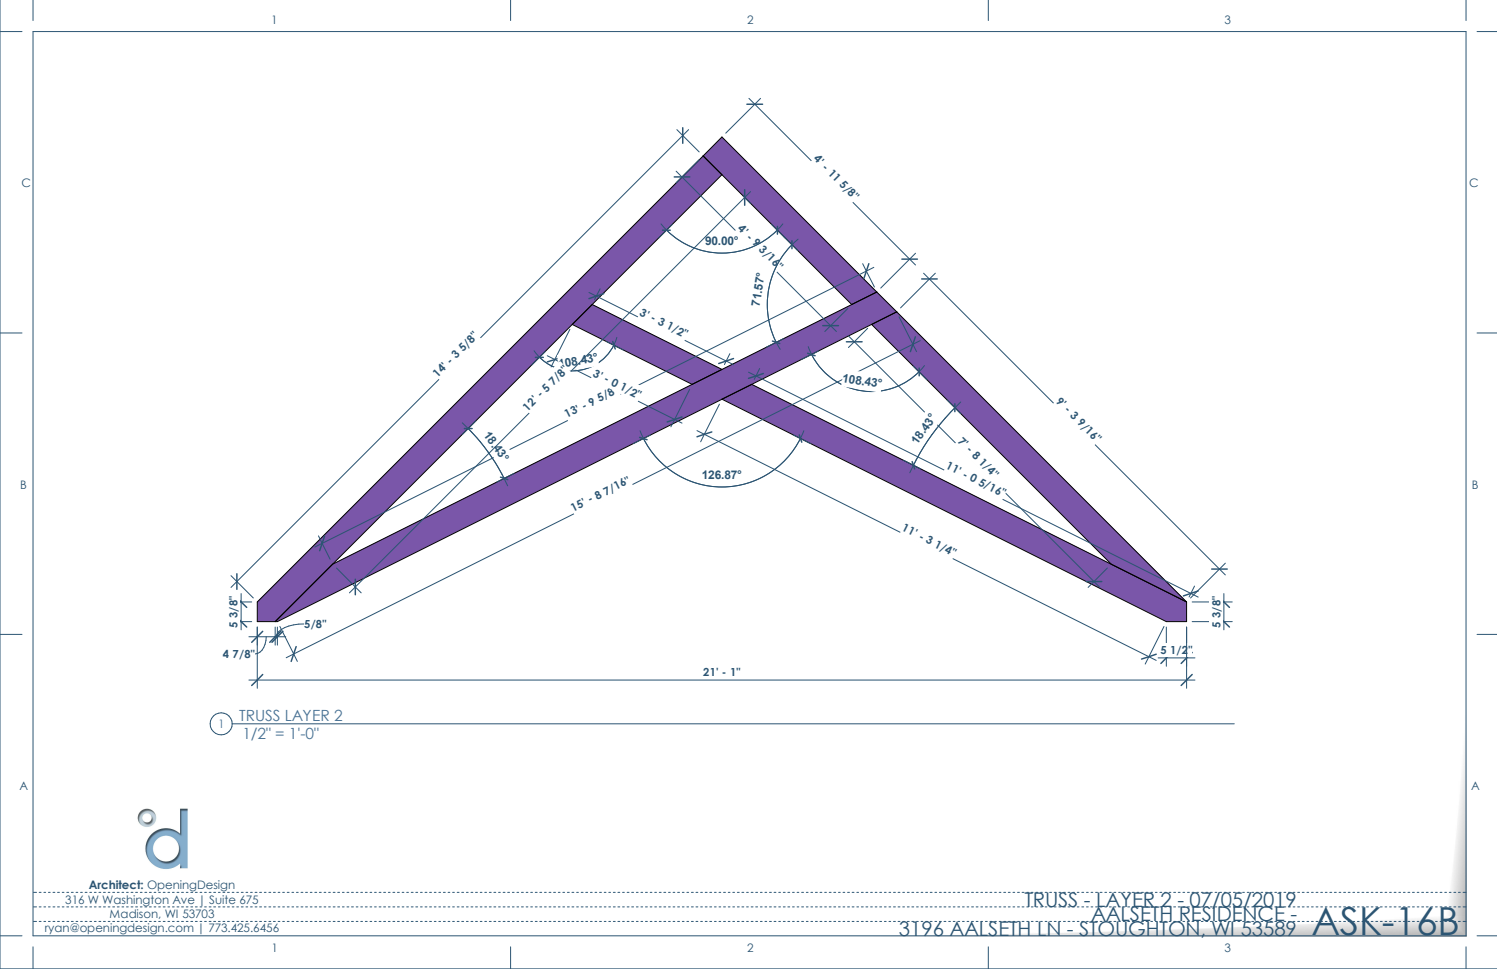
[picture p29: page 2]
Madison, WI 53703; ryan@openingdesign.com | 773.425.6456; 3196 AALSETH LN - STOUGHTON, WI 53589 AALSETH RESIDENCE - TRUSS - LAYER 2 - 07/05/2019 ASK-16B; TRUSS LAYER 2

Architect: OpeningDesign
316 W Washington Ave | Suite 675

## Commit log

2018-04-20 Project Setup
    [Uniformat comparison-ALL.xls]
2018-08-27 20180827 - to kegonsa sanitary district - review of grinder pump location
2018-12-03 20181203 - for Grinder Pump Location
2018-12-10 foundation plans to contractors
    [3196 Aalseth Lane-Sheet - A070 - SITE PLAN - TOPOGRAPHY ONLY.dwg, 3196 Aalseth Lane-Sheet - S050 - FOUNDATION PLAN.dwg, 3196 Aalseth Lane-Sheet - S051 - EXCAVA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]
2019-01-11 20190110 - ASK-01 - seam detail in concrete
    [08360-511ExterEl.dwg, 08360-511IntEl.dwg, 08360-511PnlDtl.dwg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]
2019-04-09 massive screw up
2019-05-28 20190527 - to interior designer - backgrounds
    [20190527 - 3196 Aalseth Lane-Sheet - A100 - FLOOR PLAN - BASEMENT.dwg, 20190527 - 3196 Aalseth Lane-Sheet - A101 - FLOOR PLAN - 1ST FLOOR.dwg, 20190527 - 3196 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]
2019-06-13 20190612 - to Subs - Current Set
    [20190612 - 3196 Aalseth Lane-Sheet - ASK-05 - STRUCTURE - MOMENT FRAME (1).dwg, 20190612 - 3196 Aalseth Lane-Sheet - ASK-06 - STRUCTURE - MOMENT FRAME (1) - BA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]
2019-07-15 20190715 - to Framer - Latest Set
    [20190705 - 3196 Aalseth Lane - Truss Profile-Sheet - ASK-16A - TRUSS - LAYER 1.dwg, 20190705 - 3196 Aalseth Lane - Truss Profile-Sheet - ASK-16B - TRUSS - LAYE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]
2019-10-02 gutter detail
    [3196 Aalseth Lane-Sheet - A100 - FLOOR PLAN - BASEMENT.dwg, 3196 Aalseth Lane-Sheet - A101 - FLOOR PLAN - 1ST FLOOR.dwg, 3196 Aalseth Lane-Sheet - A102 - FLOOR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]
2019-11-10 Add material definitions in Revit compatible manner
